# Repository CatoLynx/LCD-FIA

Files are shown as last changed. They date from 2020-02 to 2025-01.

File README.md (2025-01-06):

# What's this?
It's my project of converting an old LCD platform passenger information display to be fully customizable!

# BOMs
The BOM for the FIAControl main controller board can be found [here](https://catolynx.github.io/LCD-FIA/Hardware/FIAControl/bom/ibom.html).

The BOM for the FIAPi Raspberry Pi HAT adapter board can be found [here](https://catolynx.github.io/LCD-FIA/Hardware/FIAPi/bom/ibom.html).

# Pictures
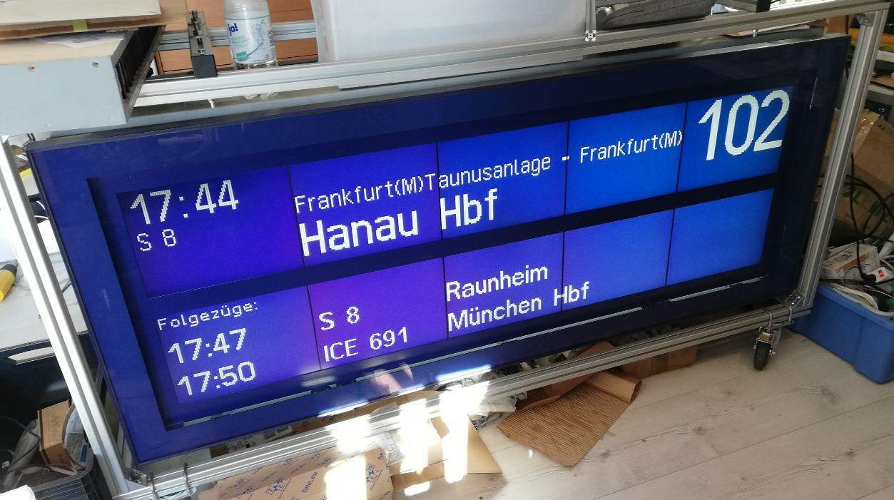
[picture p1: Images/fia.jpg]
A picture of an LCD passenger information display in my room, displaying train departures as if it was in a station


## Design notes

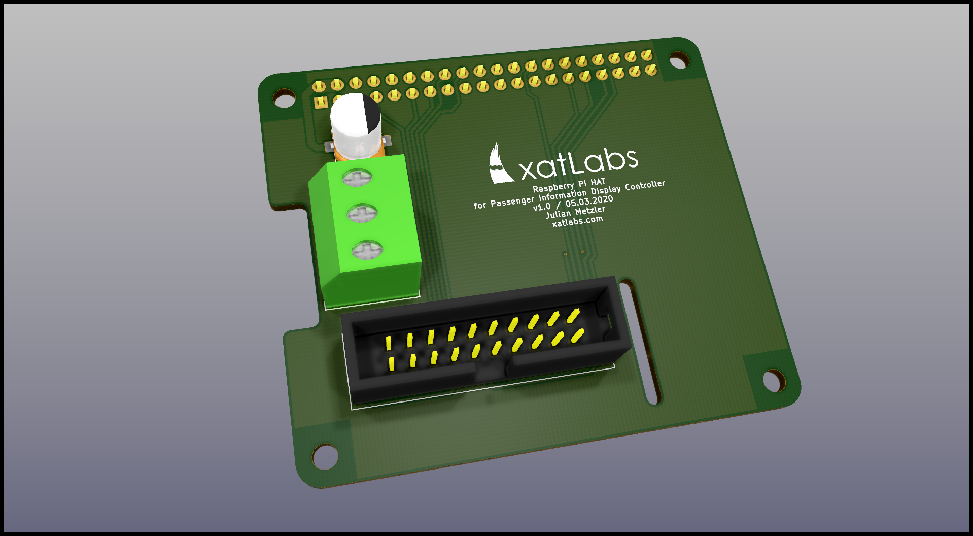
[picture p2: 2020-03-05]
Hardware/FIAPi/Images/3D Front.png

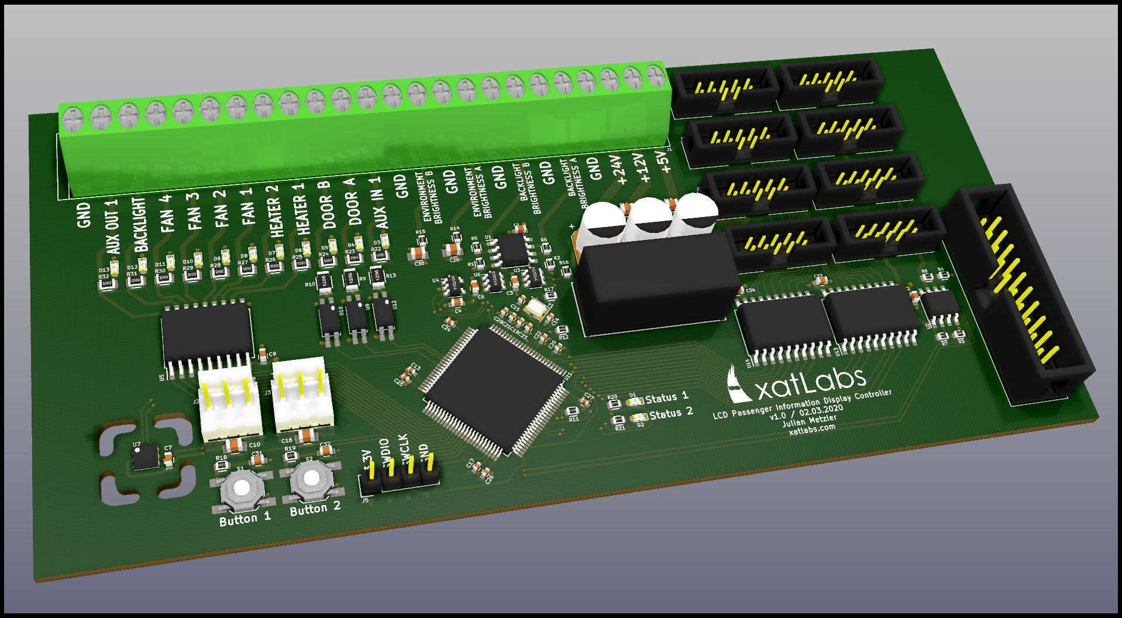
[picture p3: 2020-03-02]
Hardware/FIAControl/Images/3D Front.png

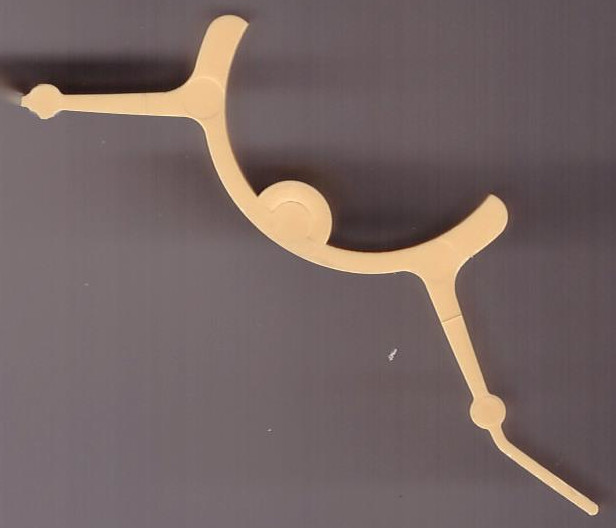
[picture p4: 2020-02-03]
CAD/LCD Klammer Scan.jpg

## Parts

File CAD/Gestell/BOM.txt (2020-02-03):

4x Profil 2060 mm (2x5 Anzeiger)
4x Profil 1810 mm (2x4 Anzeiger)
4x Profil  870 mm
4x Profil  440 mm
2x Profil  520 mm
=        14520 mm (2x5 Anzeiger)
=        13520 mm (2x4 Anzeiger)
24x Winkel
48x Nutenstein
48x Schraube
12x Abdeckkappe

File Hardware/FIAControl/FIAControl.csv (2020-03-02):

Source: | E:\Google Drive\Dokumente\Elektronik\Projekte\funkwerk KJ LCD FIA\Hardware\FIAControl\FIAControl.sch
Date: | 02.03.2020 23:40:50
Tool: | Eeschema (6.0.0-rc1-dev-557-ge985f797c)
Generator: | E:\Google Drive\configfiles\kicad-lib\scripting\plugins\bom_csv_grouped_custom.py
Component Count: | 109
Individual Components:
Item | Qty | Reference(s) | Value | LibPart | Footprint | Datasheet | Comment | Order No.
 |  | C1 | 100n | device:C | Capacitors_SMD:C_0603 | ~
 |  | C2 | 100n | device:C | Capacitors_SMD:C_0603 | ~
 |  | C3 | 100n | device:C | Capacitors_SMD:C_0603 | ~
 |  | C4 | 100n | device:C_Small | Capacitors_SMD:C_0603 | ~
 |  | C5 | 100µ/35V | device:CP | Capacitors_SMD:CP_Elec_6.3x7.7 | ~
 |  | C6 | 100n | device:C | Capacitors_SMD:C_0603 | ~
 |  | C7 | 100n | device:C_Small | Capacitors_SMD:C_0603 | ~
 |  | C8 | 100µ/35V | device:CP | Capacitors_SMD:CP_Elec_6.3x7.7 | ~
 |  | C9 | 100n | device:C | Capacitors_SMD:C_0603 | ~
 |  | C10 | 1µ | device:C_Small | Capacitors_SMD:C_0805 | ~
 |  | C11 | 10µ | device:C | Capacitors_SMD:C_0805 | ~
 |  | C12 | 100µ/35V | device:CP | Capacitors_SMD:CP_Elec_6.3x7.7 | ~
 |  | C13 | 2.2µ | device:C_Small | Capacitors_SMD:C_0402 | ~ | Max. 2Ω ESR
 |  | C14 | 18p | device:C_Small | Capacitors_SMD:C_0402 | ~
 |  | C15 | 18p | device:C_Small | Capacitors_SMD:C_0402 | ~
 |  | C16 | 1µ | device:C_Small | Capacitors_SMD:C_0805 | ~
 |  | C17 | 2.2µ | device:C_Small | Capacitors_SMD:C_0402 | ~ | Max. 2Ω ESR
 |  | C18 | 10µ | device:C | Capacitors_SMD:C_0805 | ~
 |  | C19 | 1µ | device:C_Small | Capacitors_SMD:C_0402 | ~
 |  | C20 | 100n | device:C_Small | Capacitors_SMD:C_0402 | ~
 |  | C21 | 10n | device:C_Small | Capacitors_SMD:C_0402 | ~
 |  | C22 | 100n | device:C_Small | Capacitors_SMD:C_0402 | ~
 |  | C23 | 100n | device:C_Small | Capacitors_SMD:C_0402 | ~
 |  | C24 | 100n | device:C_Small | Capacitors_SMD:C_0402 | ~
 |  | C25 | 100n | device:C_Small | Capacitors_SMD:C_0402 | ~
 |  | C26 | 100n | device:C_Small | Capacitors_SMD:C_0402 | ~
 |  | C27 | 100n | device:C_Small | Capacitors_SMD:C_0402 | ~
 |  | C28 | 1µ | device:C_Small | Capacitors_SMD:C_0805 | ~
 |  | C29 | 100n | device:C_Small | Capacitors_SMD:C_0402 | ~
 |  | C30 | 1µ | device:C_Small | Capacitors_SMD:C_0805 | ~
 |  | C31 | 100n | device:C_Small | Capacitors_SMD:C_0603 | ~
 |  | C32 | 100n | device:C_Small | Capacitors_SMD:C_0603 | ~
 |  | C33 | 100n | device:C_Small | Capacitors_SMD:C_0603 | ~
 |  | C34 | 100n | device:C_Small | Capacitors_SMD:C_0603 | ~
 |  | D1 | Status 1 | device:LED_Small | LEDs:LED_0603 | ~
 |  | D2 | Status 2 | device:LED_Small | LEDs:LED_0603 | ~
 |  | D3 | orange | device:LED | LEDs:LED_0603 | ~
 |  | D4 | orange | device:LED | LEDs:LED_0603 | ~
 |  | D5 | orange | device:LED | LEDs:LED_0603 | ~
 |  | D6 | orange | device:LED | LEDs:LED_0603 | ~
 |  | D7 | orange | device:LED | LEDs:LED_0603 | ~
 |  | D8 | orange | device:LED | LEDs:LED_0603 | ~
 |  | D9 | orange | device:LED | LEDs:LED_0603 | ~
 |  | D10 | orange | device:LED | LEDs:LED_0603 | ~
 |  | D11 | orange | device:LED | LEDs:LED_0603 | ~
 |  | D12 | orange | device:LED | LEDs:LED_0603 | ~
 |  | D13 | orange | device:LED | LEDs:LED_0603 | ~
 |  | J1 | Interface | conn:CONN_01X24 | custom:Connector_DEGSON_DG246-3.81_24pin |  |  | 8x DG246-3.81-03P
 |  | J2 | Temp Sensor 1 | conn:CONN_01X03 | custom:Molex_1718560003
 |  | J3 | Temp Sensor 2 | conn:CONN_01X03 | custom:Molex_1718560003
 |  | J4 | Control | conn:CONN_02X10 | Connectors:IDC_Header_Straight_20pins
 |  | J5 | Debug | conn:CONN_01X04 | Pin_Headers:Pin_Header_Straight_1x04
 |  | J6 | LCD 1 Out | conn:CONN_02X05 | custom:Connector_IDC_2mm_10pin_THT_Straight |  |  | DS1014-10SF1B
 |  | J7 | LCD 1 Loopback | conn:CONN_02X05 | custom:Connector_IDC_2mm_10pin_THT_Straight |  |  | DS1014-10SF1B
 |  | J8 | LCD 3 Out | conn:CONN_02X05 | custom:Connector_IDC_2mm_10pin_THT_Straight |  |  | DS1014-10SF1B
 |  | J9 | LCD 3 Loopback | conn:CONN_02X05 | custom:Connector_IDC_2mm_10pin_THT_Straight |  |  | DS1014-10SF1B
 |  | J10 | LCD 2 Out | conn:CONN_02X05 | custom:Connector_IDC_2mm_10pin_THT_Straight |  |  | DS1014-10SF1B
 |  | J11 | LCD 2 Loopback | conn:CONN_02X05 | custom:Connector_IDC_2mm_10pin_THT_Straight |  |  | DS1014-10SF1B
 |  | J12 | LCD 4 Out | conn:CONN_02X05 | custom:Connector_IDC_2mm_10pin_THT_Straight |  |  | DS1014-10SF1B
 |  | J13 | LCD 4 Loopback | conn:CONN_02X05 | custom:Connector_IDC_2mm_10pin_THT_Straight |  |  | DS1014-10SF1B
 |  | R1 | 22k | device:R | Resistors_SMD:R_0603 | ~
 |  | R2 | 22k | device:R | Resistors_SMD:R_0603 | ~
 |  | R3 | 56k | device:R | Resistors_SMD:R_0603 | ~
 |  | R4 | 56k | device:R | Resistors_SMD:R_0603 | ~
 |  | R5 | 47k | device:R | Resistors_SMD:R_0603 | ~
 |  | R6 | 47k | device:R | Resistors_SMD:R_0603 | ~
 |  | R7 | 91k | device:R | Resistors_SMD:R_0603 | ~
 |  | R8 | 91k | device:R | Resistors_SMD:R_0603 | ~
 |  | R9 | 1.5k | device:R | Resistors_SMD:R_1206 | ~ | ca. 0.32W
 |  | R10 | 1.5k | device:R | Resistors_SMD:R_1206 | ~ | ca. 0.32W
 |  | R11 | 10k | device:R_Small | Resistors_SMD:R_0603 | ~
 |  | R12 | 10k | device:R_Small | Resistors_SMD:R_0603 | ~
 |  | R13 | 1.5k | device:R | Resistors_SMD:R_1206 | ~ | ca. 0.32W
 |  | R14 | 10k | device:R_Small | Resistors_SMD:R_0603 | ~
 |  | R15 | 10k | device:R_Small | Resistors_SMD:R_0603 | ~
 |  | R16 | 4.7k | device:R_Small | Resistors_SMD:R_0603 | ~
 |  | R17 | 4.7k | device:R_Small | Resistors_SMD:R_0603 | ~
 |  | R18 | 1k | device:R_Small | Resistors_SMD:R_0603 | ~
 |  | R19 | 1k | device:R_Small | Resistors_SMD:R_0603 | ~
 |  | R20 | 270R | device:R_Small | Resistors_SMD:R_0603 | ~
 |  | R21 | 270R | device:R_Small | Resistors_SMD:R_0603 | ~
 |  | R22 | 4.7k | device:R | Resistors_SMD:R_0805 | ~ | ca. 0.1W
 |  | R23 | 4.7k | device:R | Resistors_SMD:R_0805 | ~ | ca. 0.1W
 |  | R24 | 4.7k | device:R | Resistors_SMD:R_0805 | ~ | ca. 0.1W
 |  | R25 | 4.7k | device:R | Resistors_SMD:R_0805 | ~ | ca. 0.1W
 |  | R26 | 4.7k | device:R | Resistors_SMD:R_0805 | ~ | ca. 0.1W
 |  | R27 | 4.7k | device:R | Resistors_SMD:R_0805 | ~ | ca. 0.1W
 |  | R28 | 4.7k | device:R | Resistors_SMD:R_0805 | ~ | ca. 0.1W
 |  | R29 | 4.7k | device:R | Resistors_SMD:R_0805 | ~ | ca. 0.1W
 |  | R30 | 4.7k | device:R | Resistors_SMD:R_0805 | ~ | ca. 0.1W
 |  | R31 | 4.7k | device:R | Resistors_SMD:R_0805 | ~ | ca. 0.1W
 |  | R32 | 4.7k | device:R | Resistors_SMD:R_0805 | ~ | ca. 0.1W
 |  | S1 | Button 1 | custom:Switch_small | Buttons_Switches_SMD:SW_SPST_SKQG
 |  | S2 | Button 2 | custom:Switch_small | Buttons_Switches_SMD:SW_SPST_SKQG
 |  | U1 | LM258ADT | Amplifier_Operational:LM358 | Housings_SOIC:SOIC-8_3.9x4.9mm_Pitch1.27mm | http://www.ti.com/lit/ds/symlink/lm2904-n.pdf
 |  | U2 | LM258ADT | Amplifier_Operational:LM358 | Housings_SOIC:SOIC-8_3.9x4.9mm_Pitch1.27mm | http://www.ti.com/lit/ds/symlink/lm2904-n.pdf
 |  | U3 | MCP4726A0 | custom:MCP47x6 | TO_SOT_Packages_SMD:SOT-23-6
 |  | U4 | 24CW160T | custom:EEPROM_I2C_NO_WP | TO_SOT_Packages_SMD:SOT-23-5
 |  | U5 | MIC2981/82YWM | custom:UDN2981A | Housings_SOIC:SOIC-18W_7.5x11.6mm_Pitch1.27mm
 |  | U6 | MCP4726A1 | custom:MCP47x6 | TO_SOT_Packages_SMD:SOT-23-6
 |  | U7 | SHT21 | custom:SHT21 | custom:DFN6_3mmx3mm_EP_P1mm
 |  | U8 | SPAN02A-03 | custom:DCDC_MeanWell_SPAN | custom:DC_DC_Converter_MeanWell_SPAN
 |  | U9 | HMHA2801AR2V | Isolator:PC817 | custom:Optocoupler_MiniFlat_HalfPitch_4pin_SMD | http://www.soselectronic.cz/a_info/resource/d/pc817.pdf
 |  | U10 | HMHA2801AR2V | Isolator:PC817 | custom:Optocoupler_MiniFlat_HalfPitch_4pin_SMD | http://www.soselectronic.cz/a_info/resource/d/pc817.pdf
 |  | U11 | STM32F413VGT6 | MCU_ST_STM32F4:STM32F413VGTx | Housings_QFP:LQFP-100_14x14mm_Pitch0.5mm | http://www.st.com/st-web-ui/static/active/en/resource/technical/document/datasheet/DM00282249.pdf
 |  | U12 | HMHA2801AR2V | Isolator:PC817 | custom:Optocoupler_MiniFlat_HalfPitch_4pin_SMD | http://www.soselectronic.cz/a_info/resource/d/pc817.pdf
 |  | U13 | 74HCT541 | 74xx:74HCT541 | Housings_SOIC:SOIC-20W_7.5x12.8mm_Pitch1.27mm | http://www.ti.com/lit/gpn/sn74HCT541
 |  | U14 | 74HCT541 | 74xx:74HCT541 | Housings_SOIC:SOIC-20W_7.5x12.8mm_Pitch1.27mm | http://www.ti.com/lit/gpn/sn74HCT541
 |  | Y1 | 20MHz | device:Crystal_GND24 | Crystals:Crystal_SMD_2520-4pin_2.5x2.0mm | ~ |  | LFXTAL052896CUTT
Collated Components:
Item | Qty | Reference(s) | Value | LibPart | Footprint | Datasheet | Comment | Order No.
1 | 11 | C1,C2,C3,C4,C6,C7,C9,C31,C32,C33,C34 | 100n | device:C_Small | Capacitors_SMD:C_0603 | ~
2 | 3 | C5,C8,C12 | 100µ/35V | device:CP | Capacitors_SMD:CP_Elec_6.3x7.7 | ~
3 | 4 | C10,C16,C28,C30 | 1µ | device:C_Small | Capacitors_SMD:C_0805 | ~
4 | 2 | C11,C18 | 10µ | device:C | Capacitors_SMD:C_0805 | ~
5 | 2 | C13,C17 | 2.2µ | device:C_Small | Capacitors_SMD:C_0402 | ~ | Max. 2Ω ESR
6 | 2 | C14,C15 | 18p | device:C_Small | Capacitors_SMD:C_0402 | ~
7 | 1 | C19 | 1µ | device:C_Small | Capacitors_SMD:C_0402 | ~
8 | 8 | C20,C22,C23,C24,C25,C26,C27,C29 | 100n | device:C_Small | Capacitors_SMD:C_0402 | ~
9 | 1 | C21 | 10n | device:C_Small | Capacitors_SMD:C_0402 | ~
10 | 1 | D1 | Status 1 | device:LED_Small | LEDs:LED_0603 | ~
11 | 1 | D2 | Status 2 | device:LED_Small | LEDs:LED_0603 | ~
12 | 11 | D3,D4,D5,D6,D7,D8,D9,D10,D11,D12,D13 | orange | device:LED | LEDs:LED_0603 | ~
13 | 1 | J1 | Interface | conn:CONN_01X24 | custom:Connector_DEGSON_DG246-3.81_24pin |  |  | 8x DG246-3.81-03P
14 | 1 | J2 | Temp Sensor 1 | conn:CONN_01X03 | custom:Molex_1718560003
15 | 1 | J3 | Temp Sensor 2 | conn:CONN_01X03 | custom:Molex_1718560003
16 | 1 | J4 | Control | conn:CONN_02X10 | Connectors:IDC_Header_Straight_20pins
17 | 1 | J5 | Debug | conn:CONN_01X04 | Pin_Headers:Pin_Header_Straight_1x04
18 | 1 | J6 | LCD 1 Out | conn:CONN_02X05 | custom:Connector_IDC_2mm_10pin_THT_Straight |  |  | DS1014-10SF1B
19 | 1 | J7 | LCD 1 Loopback | conn:CONN_02X05 | custom:Connector_IDC_2mm_10pin_THT_Straight |  |  | DS1014-10SF1B
20 | 1 | J8 | LCD 3 Out | conn:CONN_02X05 | custom:Connector_IDC_2mm_10pin_THT_Straight |  |  | DS1014-10SF1B
21 | 1 | J9 | LCD 3 Loopback | conn:CONN_02X05 | custom:Connector_IDC_2mm_10pin_THT_Straight |  |  | DS1014-10SF1B
22 | 1 | J10 | LCD 2 Out | conn:CONN_02X05 | custom:Connector_IDC_2mm_10pin_THT_Straight |  |  | DS1014-10SF1B
23 | 1 | J11 | LCD 2 Loopback | conn:CONN_02X05 | custom:Connector_IDC_2mm_10pin_THT_Straight |  |  | DS1014-10SF1B
24 | 1 | J12 | LCD 4 Out | conn:CONN_02X05 | custom:Connector_IDC_2mm_10pin_THT_Straight |  |  | DS1014-10SF1B
25 | 1 | J13 | LCD 4 Loopback | conn:CONN_02X05 | custom:Connector_IDC_2mm_10pin_THT_Straight |  |  | DS1014-10SF1B
26 | 2 | R1,R2 | 22k | device:R | Resistors_SMD:R_0603 | ~
27 | 2 | R3,R4 | 56k | device:R | Resistors_SMD:R_0603 | ~
28 | 2 | R5,R6 | 47k | device:R | Resistors_SMD:R_0603 | ~
29 | 2 | R7,R8 | 91k | device:R | Resistors_SMD:R_0603 | ~
30 | 3 | R9,R10,R13 | 1.5k | device:R | Resistors_SMD:R_1206 | ~ | ca. 0.32W
31 | 4 | R11,R12,R14,R15 | 10k | device:R_Small | Resistors_SMD:R_0603 | ~
32 | 2 | R16,R17 | 4.7k | device:R_Small | Resistors_SMD:R_0603 | ~
33 | 2 | R18,R19 | 1k | device:R_Small | Resistors_SMD:R_0603 | ~
34 | 2 | R20,R21 | 270R | device:R_Small | Resistors_SMD:R_0603 | ~
35 | 11 | R22,R23,R24,R25,R26,R27,R28,R29,R30,R31,R32 | 4.7k | device:R | Resistors_SMD:R_0805 | ~ | ca. 0.1W
36 | 1 | S1 | Button 1 | custom:Switch_small | Buttons_Switches_SMD:SW_SPST_SKQG
37 | 1 | S2 | Button 2 | custom:Switch_small | Buttons_Switches_SMD:SW_SPST_SKQG
38 | 2 | U1,U2 | LM258ADT | Amplifier_Operational:LM358 | Housings_SOIC:SOIC-8_3.9x4.9mm_Pitch1.27mm | http://www.ti.com/lit/ds/symlink/lm2904-n.pdf
39 | 1 | U3 | MCP4726A0 | custom:MCP47x6 | TO_SOT_Packages_SMD:SOT-23-6
40 | 1 | U4 | 24CW160T | custom:EEPROM_I2C_NO_WP | TO_SOT_Packages_SMD:SOT-23-5
41 | 1 | U5 | MIC2981/82YWM | custom:UDN2981A | Housings_SOIC:SOIC-18W_7.5x11.6mm_Pitch1.27mm
42 | 1 | U6 | MCP4726A1 | custom:MCP47x6 | TO_SOT_Packages_SMD:SOT-23-6
43 | 1 | U7 | SHT21 | custom:SHT21 | custom:DFN6_3mmx3mm_EP_P1mm
44 | 1 | U8 | SPAN02A-03 | custom:DCDC_MeanWell_SPAN | custom:DC_DC_Converter_MeanWell_SPAN
45 | 3 | U9,U10,U12 | HMHA2801AR2V | Isolator:PC817 | custom:Optocoupler_MiniFlat_HalfPitch_4pin_SMD | http://www.soselectronic.cz/a_info/resource/d/pc817.pdf
46 | 1 | U11 | STM32F413VGT6 | MCU_ST_STM32F4:STM32F413VGTx | Housings_QFP:LQFP-100_14x14mm_Pitch0.5mm | http://www.st.com/st-web-ui/static/active/en/resource/technical/document/datasheet/DM00282249.pdf
47 | 2 | U13,U14 | 74HCT541 | 74xx:74HCT541 | Housings_SOIC:SOIC-20W_7.5x12.8mm_Pitch1.27mm | http://www.ti.com/lit/gpn/sn74HCT541
48 | 1 | Y1 | 20MHz | device:Crystal_GND24 | Crystals:Crystal_SMD_2520-4pin_2.5x2.0mm | ~ |  | LFXTAL052896CUTT

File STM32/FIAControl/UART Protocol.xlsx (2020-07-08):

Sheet: General Information
Frame Structure
Pos. | Value | Description
1 | 0xFF | Start Byte
2 |  | Message length (all following bytes)
3 … n-1 |  | Payload
n |  | Checksum (XOR across all payload bytes, start value 0x7F)

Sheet: UART Commands
UART Commands
Group | Command | Name | Payload Length | Response Payload Length | Description
System | 0x00 | NULL | 0 | 1 | Dummy command. Response: Byte 0 - Always 0xFF
 | 0x01 | MCU_RESET | 0 | 0 | Initiate a system reset. No response since the system will immediately reset.
Lights | 0x10 | SET_BACKLIGHT_STATE | 1 | 0 | Set / Get backlight state. Parameters: Byte 0 - Backlight state (0 = OFF, 1 = ON)
 | 0x11 | GET_BACKLIGHT_STATE | 0 | 1
 | 0x12 | SET_BACKLICHT_BASE_BRIGHTNESS | 4 | 0 | Set / Get base value for backlight auto-brightness. (0 to 4095) Parameters: Byte 0 - Side A brightness high byte Byte 1 - Side A brightness low byte Byte 2 - Side B brightness high byte Byte 3 - Side B brightness low byte
 | 0x13 | GET_BACKLIGHT_BASE_BRIGHTNESS | 0 | 4
 | 0x14 | GET_BACKLIGHT_BRIGHTNESS | 0 | 4 | Set / Get current backlight brightness. (0 to 4095) Parameters: Byte 0 - Side A brightness high byte Byte 1 - Side A brightness low byte Byte 2 - Side B brightness high byte Byte 3 - Side B brightness low byte
Heat Management | 0x20 | SET_HEATERS_STATE | 1 | 0 | Set / Get heaters state. Parameters: Byte 0 - Heaters state (0 = OFF, 1 = HALF POWER, 2 = FULL POWER)
 | 0x21 | GET_HEATERS_STATE | 0 | 1
 | 0x22 | SET_CIRCULATION_FANS_STATE | 1 | 0 | Set / Get circulation fans state. Parameters: Byte 0 - Circulation fans state (0 = OFF, 1 = HALF POWER, 2 = FULL POWER)
 | 0x23 | GET_CIRCULATION_FANS_STATE | 0 | 1
 | 0x24 | SET_HEAT_EXCHANGER_FAN_STATE | 0 | 1 | Set / Get heat exchanger fan state. Parameters: Byte 0 - Heat exchanger fan state (0 = OFF, 1 = ON)
 | 0x25 | GET_HEAT_EXCHANGER_FAN_STATE | 1 | 0
 | 0x26 | SET_BACKLIGHT_BALLAST_FANS_STATE | 0 | 1 | Set / Get heat backlight ballast fans state. Parameters: Byte 0 - Backlight ballast fans state (0 = OFF, 1 = ON)
 | 0x27 | GET_BACKLIGHT_BALLAST_FANS_STATE | 1 | 0
Doors | 0x30 | GET_DOOR_STATES | 0 | 1 | Get door states. Parameters: Byte 0 - Door states (Bit 0 = Door A, Bit 1 = Door B; 0 = CLOSED, 1 = OPEN)
Sensors | 0x40 | GET_TEMPERATURES | 0 | 8 | Get temperature readings of internal sensors. All values are in 1/100 °C. Parameters: Byte 0 - External sensor 1 high byte Byte 1 - External sensor 1 low byte Byte 2 - External sensor 2 high byte Byte 3 - External sensor 2 low byte Byte 4 - On-board sensor high byte Byte 5 - On-board sensor low byte Byte 6 - MCU sensor high byte Byte 7 - MCU sensor low byte
 | 0x41 | GET_HUMIDITY | 0 | 2 | Get internal humidity reading from on-board sensor. Value is in 1/100 %RH. Parameters: Byte 0 - Humidity high byte Byte 1 - Humidity low byte
 | 0x42 | GET_ENV_BRIGHTNESS | 0 | 4 | Get environment brightness reading from integrated brightness sensors. (0 to 4095) Parameters: Byte 0 - Side A brightness high byte Byte 1 - Side A brightness low byte Byte 2 - Side B brightness high byte Byte 3 - Side B brightness low byte
LCDs | 0x50 | SET_LCD_CONTRAST | 4 | 0 | Set / Get current LCD contrast. (0 to 4095) Parameters: Byte 0 - Side A contrast high byte Byte 1 - Side A contrast low byte Byte 2 - Side B contrast high byte Byte 3 - Side B contrast low byte
 | 0x51 | GET_LCD_CONTRAST | 0 | 4
 | 0x60 | CREATE_SCROLL_BUFFER | 25 | 1 | Create a scroll buffer. Position and size values are in pixels. X and Y are counted from the top-left corner of the display. Parameters: Byte 0 - Display X position high byte Byte 1 - Display side Byte 2 - Display X position low byte Byte 3 - Display Y position high byte Byte 4 - Dispaly Y position low byte Byte 5 - Display width high byte Byte 6 - Display width low byte Byte 7 - Display height high byte Byte 8 - Display height low byte Byte 9 - Internal width high byte Byte 10 - Internal width low byte Byte 11 - Internal height high byte Byte 12 - Internal height low byte Byte 13 - Scroll offset X high byte Byte 14 - Scroll offset X low byte Byte 15 - Scroll offset Y high byte Byte 16 - Scroll offset Y low byte Byte 17 - Scroll speed X high byte Byte 18 - Scroll speed X low byte Byte 19 - Scroll speed Y high byte Byte 20 - Scroll speed Y low byte Byte 21 - Scroll step X high byte Byte 22 - Scroll step X low byte Byte 23 - Scroll step Y high byte Byte 24 - Scroll step Y low byte Response: Byte 0 - The ID of the created buffer or 0 on failure
 | 0x61 | DELETE_SCROLL_BUFFER | 1 | 1 | Delete a scroll buffer. Parameters: Byte 0 - The ID of the buffer to be deleted Response: Byte 0 - 1 on success, 0 on failure
 | 0x62 | UPDATE_SCROLL_BUFFER | 22 | 1 | Update parameters of a scroll buffer. Position and size values are in pixels. X and Y are counted from the top-left corner of the display. Set any value to 0xFFFF (0x7FFF for scroll steps) to leave unchanged. Parameters: Byte 0 - The ID of the buffer to be updated Byte 1 - Display side Byte 2 - Display X position high byte Byte 3 - Display X position low byte Byte 4 - Display Y position high byte Byte 5 - Dispaly Y position low byte Byte 6 - Display width high byte Byte 7 - Display width low byte Byte 8 - Display height high byte Byte 9 - Display height low byte Byte 10 - Scroll offset X high byte Byte 11 - Scroll offset X low byte Byte 12 - Scroll offset Y high byte Byte 13 - Scroll offset Y low byte Byte 14 - Scroll speed X high byte Byte 15 - Scroll speed X low byte Byte 16 - Scroll speed Y high byte Byte 17 - Scroll speed Y low byte Byte 18 - Scroll step X high byte Byte 19 - Scroll step X low byte Byte 20 - Scroll step Y high byte Byte 21 - Scroll step Y low byte Response: Byte 0 - 1 on success, 0 on failure
 | 0x63 | SET_DESTINATION_BUFFER | 1 | 1 | Set the SPI destination buffer. Parameters: Byte 0 - The ID of the destination buffer Response: Byte 0 - 1 on success, 0 on failure
 | 0x64 | GET_DESTINATION_BUFFER | 0 | 1 | Get the SPI destination buffer. Response: Byte 0 - The buffer ID as expected by SET_DESTINATION_BUFFER
 | 0x65 | SET_MASK_ENABLED | 1 | 0 | Set mask compositing on or off. Parameters: Byte 0 - 1 for on, 0 for off
 | 0x66 | GET_MASK_ENABLED | 0 | 1 | Return mask compositing state. Response: Byte 0 - 1 for on, 0 for off

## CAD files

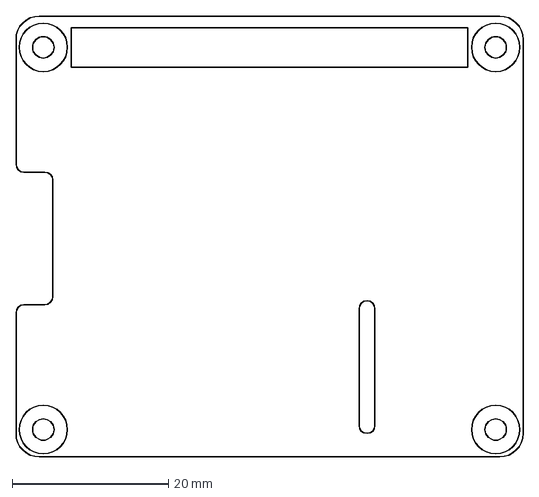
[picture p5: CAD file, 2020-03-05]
Hardware/FIAPi/HAT.dxf
65.0 x 56.5 mm

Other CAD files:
CAD/Gestell/Anzeiger Typ 5.STL
CAD/Gestell/Gestell.STL
CAD/LCD Klammer.STL
CAD/LCD Klammer.dxf

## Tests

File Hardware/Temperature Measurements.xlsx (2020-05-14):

Time | Temp. Backlight Ballasts | Temp. Airflow | Temp. Board | Temp. MCU | Rel. Humidity
0 | 32.31 | 28.25 | 32.11 | 32.7 | 17.89
5.02286005 | 32.25 | 28.25 | 32.1 | 32.7 | 17.89
10.04397988 | 32.25 | 28.25 | 32.1 | 32.7 | 17.86
15.06609988 | 32.18 | 28.25 | 32.1 | 33.02 | 17.86
20.08723998 | 32.18 | 28.18 | 32.1 | 33.02 | 17.86
25.10895991 | 32.12 | 28.25 | 32.21 | 33.02 | 17.86
30.13077998 | 32.12 | 28.18 | 32.21 | 33.35 | 17.74
35.1519599 | 32.12 | 28.25 | 32.21 | 33.35 | 17.74
40.1742599 | 32.12 | 28.25 | 32.21 | 33.35 | 17.74
45.19580984 | 32.12 | 28.25 | 32.3 | 33.35 | 17.74
50.21706986 | 32.18 | 28.25 | 32.3 | 33.35 | 17.7
55.23914003 | 32.18 | 28.25 | 32.3 | 33.35 | 17.7
60.26086998 | 32.25 | 28.25 | 32.3 | 33.35 | 17.7
65.28291988 | 32.31 | 28.18 | 32.26 | 33.35 | 17.7
70.30535984 | 32.37 | 28.25 | 32.26 | 33.35 | 17.78
75.32747984 | 32.37 | 28.25 | 32.26 | 33.35 | 17.78
80.34875989 | 32.5 | 28.25 | 32.26 | 33.35 | 17.78
85.36996984 | 32.56 | 28.25 | 32.22 | 33.35 | 17.78
90.39227986 | 32.62 | 28.31 | 32.22 | 33.35 | 17.86
95.41399002 | 32.75 | 28.25 | 32.22 | 33.35 | 17.86
100.4358299 | 32.81 | 28.31 | 32.22 | 33.35 | 17.86
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

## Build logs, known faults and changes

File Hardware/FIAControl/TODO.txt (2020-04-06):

- Contrast OP-Amp: Must be more powerful and source / sink current
- OneWire: Missing pull-up resistors
- Env. Backlight input: Doesn't go down to 0V
- Change peripheral connectors (maybe even use pluggable connectors)

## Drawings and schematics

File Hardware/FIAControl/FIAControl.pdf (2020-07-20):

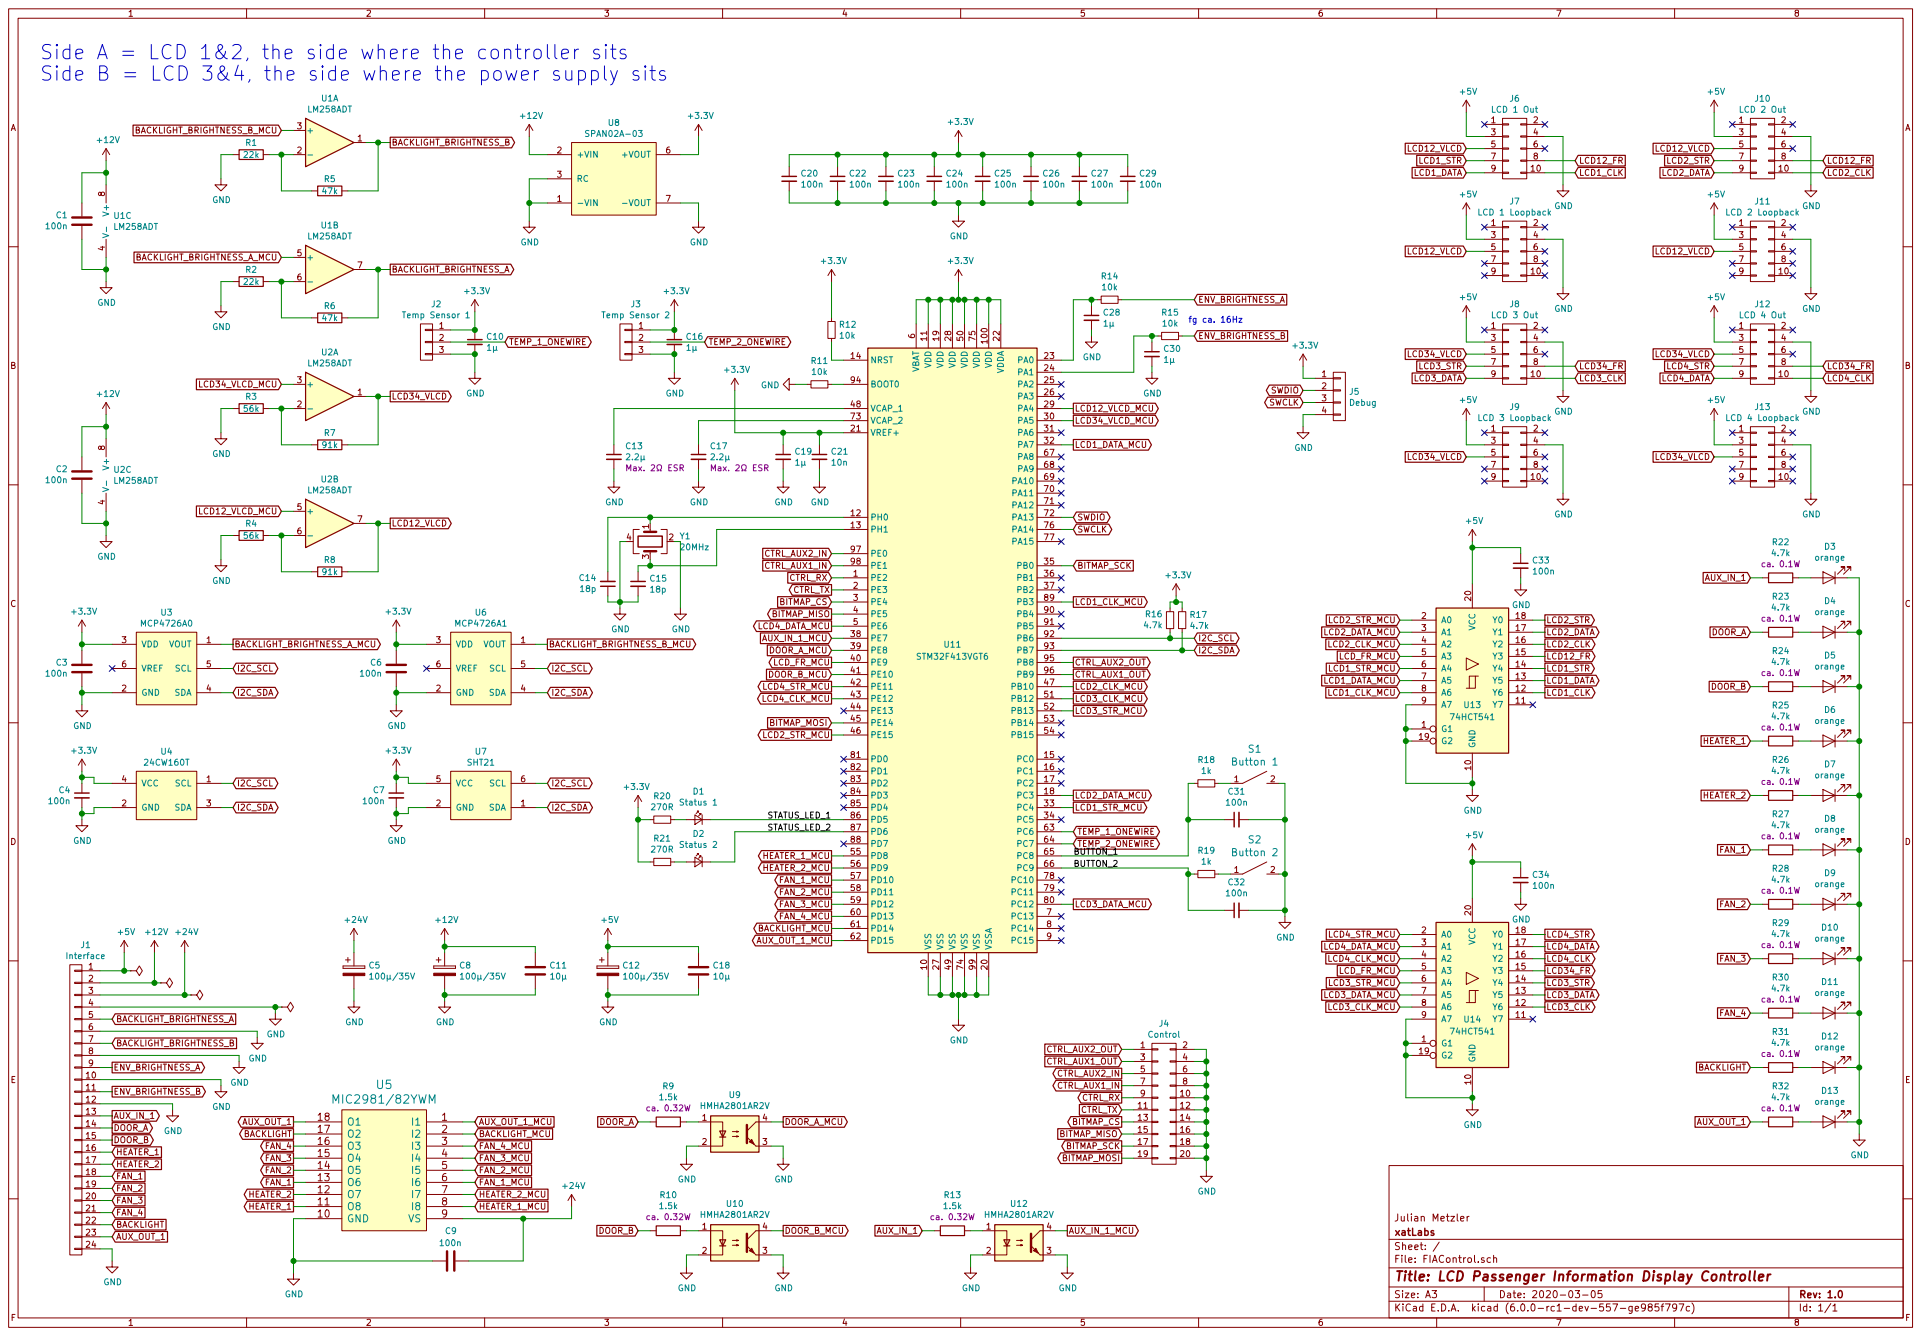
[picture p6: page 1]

LCD12_VLCD_MCU Side A = LCD 1&2, the side where the controller sits
Side B = LCD 3&4, the side where the power supply sits

6 VCAP_1 48 VCAP_2 73 VDD 100 VDD 11 VDD 19 VDD 28 VDD 50 VDD 75 VDDA 22 VREF+ 21 VSS 10 VSS 27 VSS 49 VSS 74 VSS 99 VSSA 20 U11 STM32F413VGT6 GND

Julian Metzler
Id: 1/1 Title: LCD Passenger Information Display Controller File: FIAControl.sch Sheet: / xatLabs

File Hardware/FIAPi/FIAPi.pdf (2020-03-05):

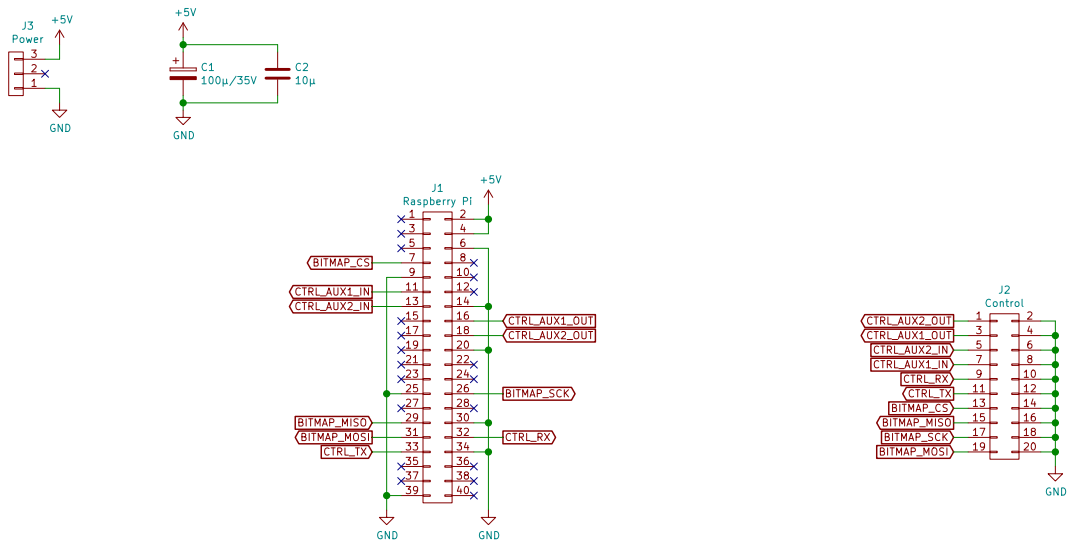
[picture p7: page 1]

Julian Metzler
File: FIAPi.sch Sheet: / xatLabs

Id: 1/1 Title: FIA Raspberry Pi HAT

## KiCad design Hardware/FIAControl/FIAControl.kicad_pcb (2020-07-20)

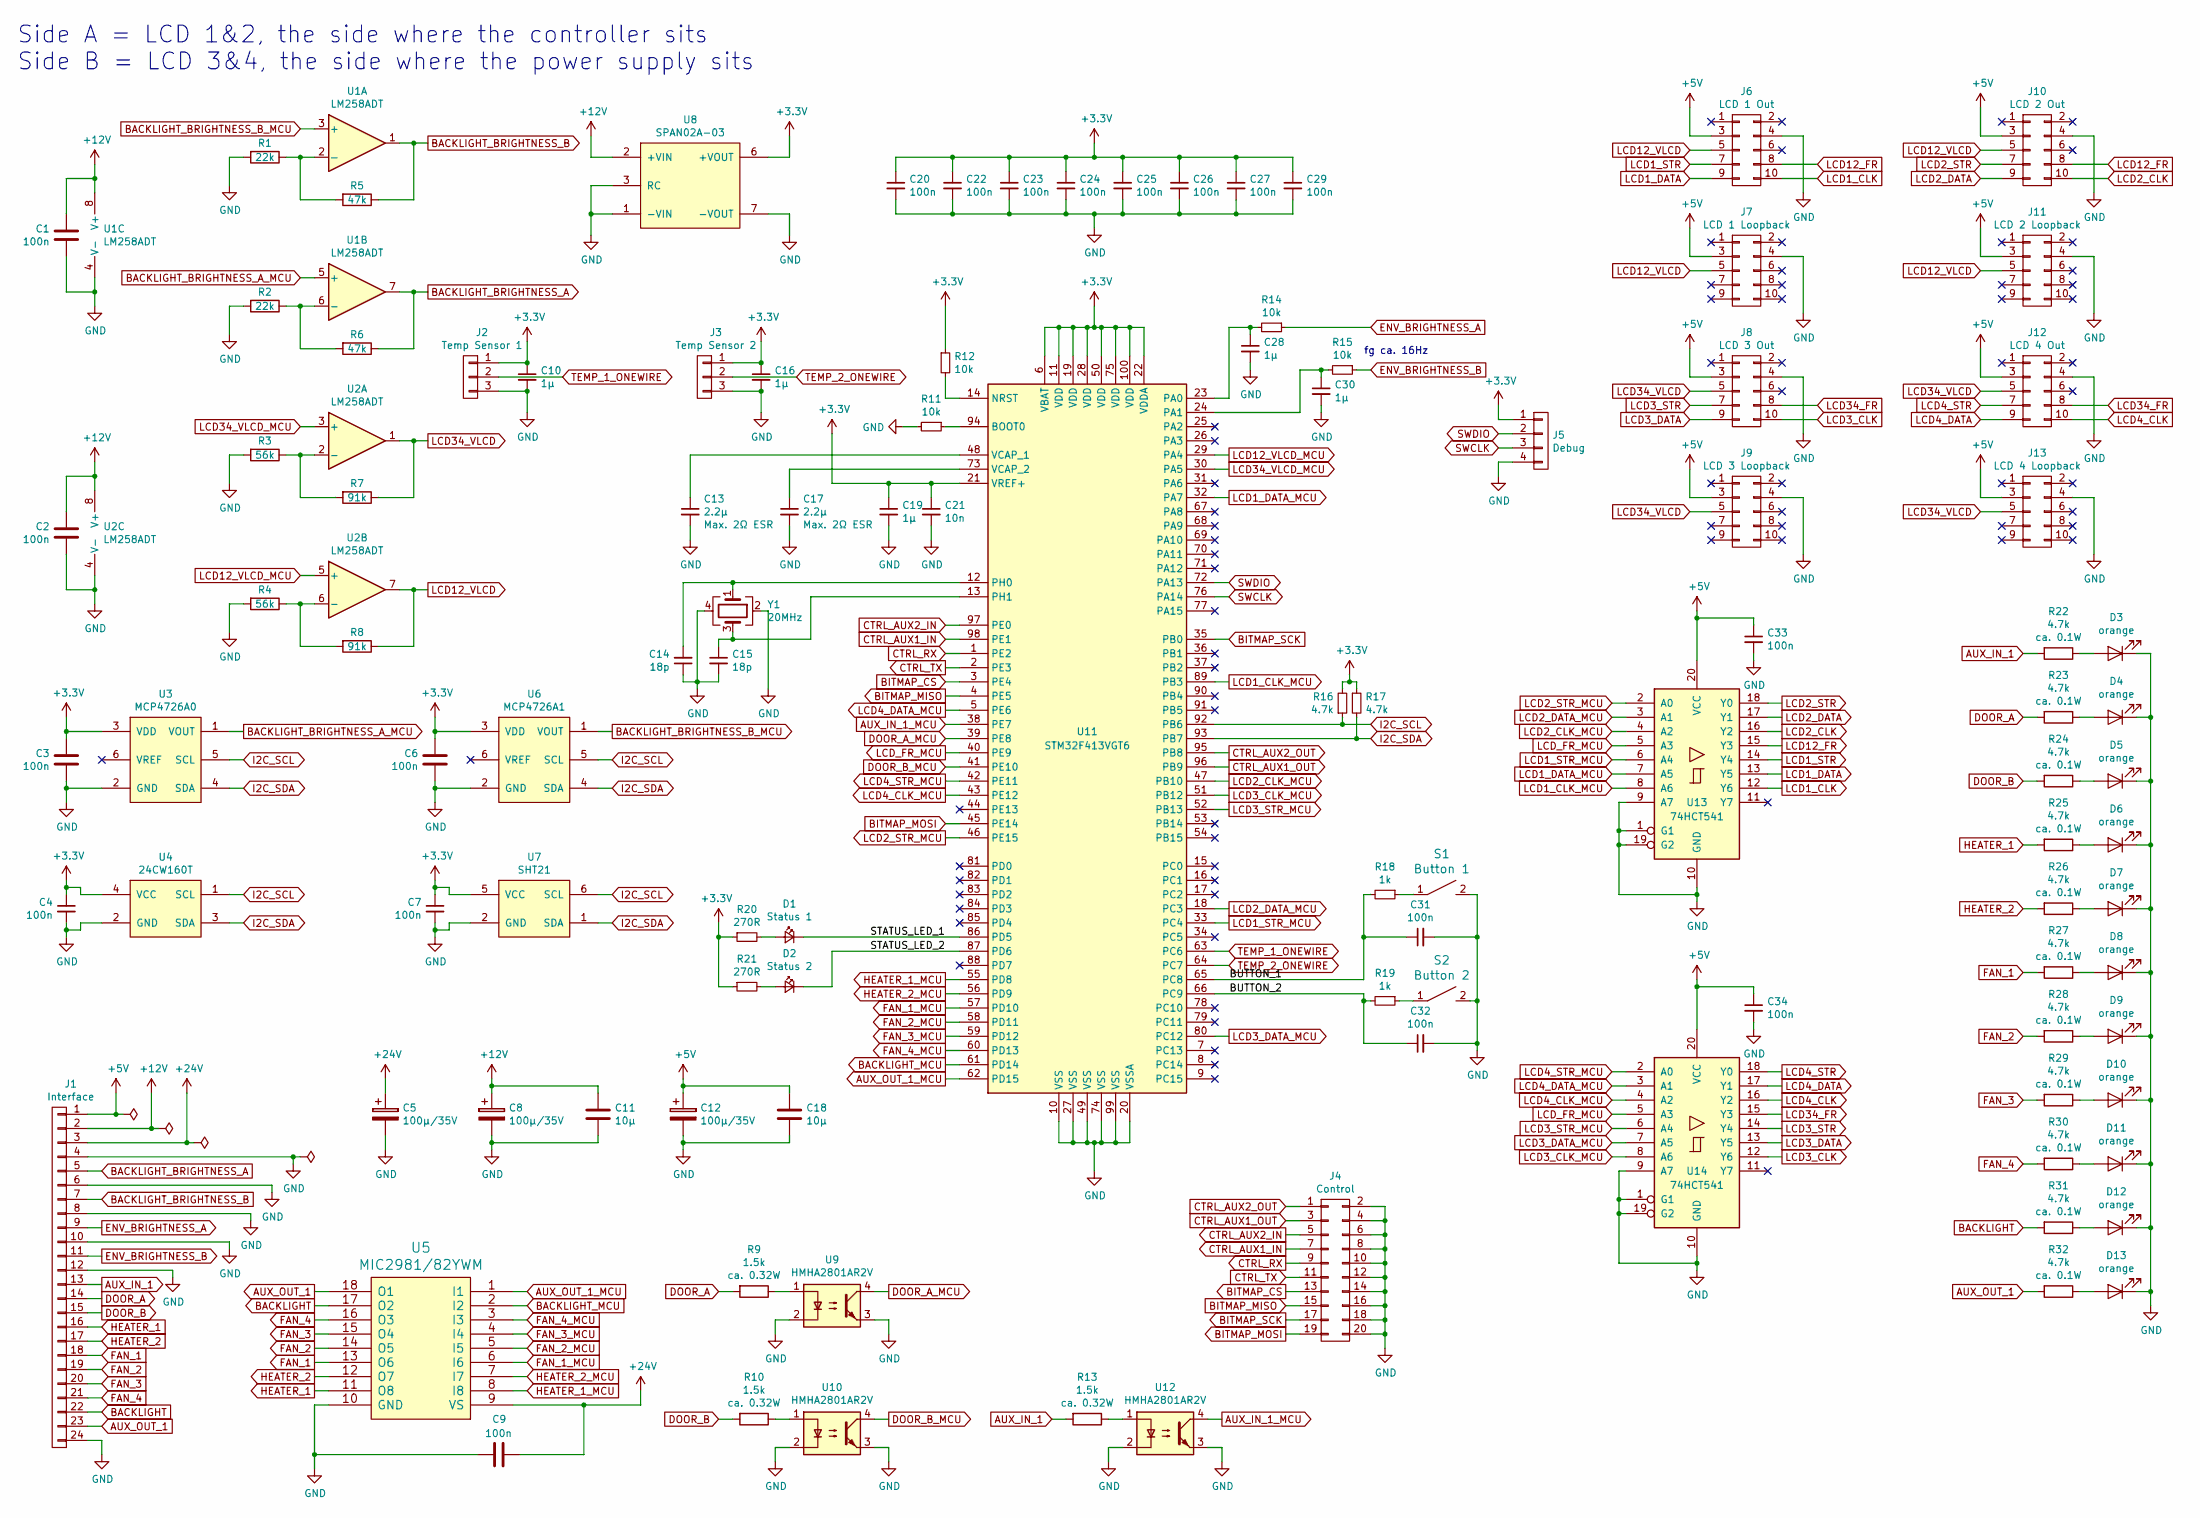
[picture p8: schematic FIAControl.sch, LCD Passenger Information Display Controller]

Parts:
C1, C2, C3, C4, C6, C7, C9, C31, C32, C33, C34: 100n; C_0603
C5, C8, C12: 100µ/35V; CP_Elec_6.3x7.7
C10, C16, C28, C30: 1µ; C_0805
C11, C18: 10µ; C_0805
C13, C17: 2.2µ; C_0402
C14, C15: 18p; C_0402
C19: 1µ; C_0402
C20, C22, C23, C24, C25, C26, C27, C29: 100n; C_0402
C21: 10n; C_0402
D1: Status 1; LED_0603
D2: Status 2; LED_0603
D3, D4, D5, D6, D7, D8, D9, D10, D11, D12, D13: orange; LED_0603
J1: Interface; Connector_DEGSON_DG246-3.81_24pin
J2: Temp Sensor 1; Molex_1718560003
J3: Temp Sensor 2; Molex_1718560003
J4: Control; IDC_Header_Straight_20pins
J5: Debug; Pin_Header_Straight_1x04
J6: LCD 1 Out; Connector_IDC_2mm_10pin_THT_Straight
J7: LCD 1 Loopback; Connector_IDC_2mm_10pin_THT_Straight
J8: LCD 3 Out; Connector_IDC_2mm_10pin_THT_Straight
J9: LCD 3 Loopback; Connector_IDC_2mm_10pin_THT_Straight
J10: LCD 2 Out; Connector_IDC_2mm_10pin_THT_Straight
J11: LCD 2 Loopback; Connector_IDC_2mm_10pin_THT_Straight
J12: LCD 4 Out; Connector_IDC_2mm_10pin_THT_Straight
J13: LCD 4 Loopback; Connector_IDC_2mm_10pin_THT_Straight
R1, R2: 22k; R_0603
R3, R4: 56k; R_0603
R5, R6: 47k; R_0603
R7, R8: 91k; R_0603
R9, R10, R13: 1.5k; R_1206
R11, R12, R14, R15: 10k; R_0603
R16, R17: 4.7k; R_0603
R18, R19: 1k; R_0603
R20, R21: 270R; R_0603
R22, R23, R24, R25, R26, R27, R28, R29, R30, R31, R32: 4.7k; R_0805
S1: Button 1; SW_SPST_SKQG
S2: Button 2; SW_SPST_SKQG
U1, U2: LM258ADT; SOIC-8_3.9x4.9mm_Pitch1.27mm
U3: MCP4726A0; SOT-23-6
U4: 24CW160T; SOT-23-5
U5: MIC2981/82YWM; SOIC-18W_7.5x11.6mm_Pitch1.27mm
U6: MCP4726A1; SOT-23-6
U7: SHT21; DFN6_3mmx3mm_EP_P1mm
U8: SPAN02A-03; DC_DC_Converter_MeanWell_SPAN
U9, U10, U12: HMHA2801AR2V; Optocoupler_MiniFlat_HalfPitch_4pin_SMD
U11: STM32F413VGT6; LQFP-100_14x14mm_Pitch0.5mm
U13, U14: 74HCT541; SOIC-20W_7.5x12.8mm_Pitch1.27mm
Y1: 20MHz; Crystal_SMD_2520-4pin_2.5x2.0mm

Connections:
+3V3: C3.2, C4.1, C6.2, C7.1, C10.1, C16.1, C19.1, C20.1, C21.1, C22.1, C23.1, C24.1, C25.1, C26.1, C27.1, C29.1, J2.1, J3.1, J5.1, R12.1, R16.2, R17.1, R20.1, R21.1, U3.3 (VDD), U4.4 (VCC), U6.3 (VDD), U7.5 (VCC), U8.6 (+VOUT), U11.6 (VBAT), U11.11 (VDD), U11.19 (VDD), U11.21 (VREF+), U11.22 (VDDA), U11.28 (VDD), U11.50 (VDD), U11.75 (VDD), U11.100 (VDD)
+5V: C12.1, C18.1, C33.1, C34.1, J1.1, J6.3, J7.3, J8.3, J9.3, J10.3, J11.3, J12.3, J13.3, U13.20 (VCC), U14.20 (VCC)
+12V: C1.2, C2.2, C8.1, C11.1, J1.2, U1.8 (V+), U2.8 (V+), U8.2 (+VIN)
+24V: C5.1, C9.2, J1.3, U5.9 (VS)
/BUTTON_1: C31.1, R18.2, U11.65 (PC8)
/BUTTON_2: C32.1, R19.2, U11.66 (PC9)
/STATUS_LED_1: D1.1 (K), U11.86 (PD5)
/STATUS_LED_2: D2.1 (K), U11.87 (PD6)
AUX_IN_1: J1.13, R13.2, R22.2
AUX_IN_1_MCU: U11.38 (PE7), U12.4
AUX_OUT_1: J1.23, R32.2, U5.18 (O1)
AUX_OUT_1_MCU: U5.1 (I1), U11.62 (PD15)
BACKLIGHT: J1.22, R31.2, U5.17 (O2)
BACKLIGHT_BRIGHTNESS_A: J1.5, R6.1, U1.7
BACKLIGHT_BRIGHTNESS_A_MCU: U1.5 (+), U3.1 (VOUT)
BACKLIGHT_BRIGHTNESS_B: J1.7, R5.1, U1.1
BACKLIGHT_BRIGHTNESS_B_MCU: U1.3 (+), U6.1 (VOUT)
BACKLIGHT_MCU: U5.2 (I2), U11.61 (PD14)
BITMAP_CS: J4.13, U11.3 (PE4)
BITMAP_MISO: J4.15, U11.4 (PE5)
BITMAP_MOSI: J4.19, U11.45 (PE14)
BITMAP_SCK: J4.17, U11.35 (PB0)
CTRL_AUX1_IN: J4.7, U11.98 (PE1)
CTRL_AUX1_OUT: J4.3, U11.96 (PB9)
CTRL_AUX2_IN: J4.5, U11.97 (PE0)
CTRL_AUX2_OUT: J4.1, U11.95 (PB8)
CTRL_RX: J4.9, U11.1 (PE2)
CTRL_TX: J4.11, U11.2 (PE3)
DOOR_A: J1.14, R9.2, R23.2
DOOR_A_MCU: U9.4, U11.39 (PE8)
DOOR_B: J1.15, R10.2, R24.2
DOOR_B_MCU: U10.4, U11.41 (PE10)
ENV_BRIGHTNESS_A: J1.9, R14.1
ENV_BRIGHTNESS_B: J1.11, R15.1
FAN_1: J1.18, R27.2, U5.13 (O6)
FAN_1_MCU: U5.6 (I6), U11.57 (PD10)
FAN_2: J1.19, R28.2, U5.14 (O5)
FAN_2_MCU: U5.5 (I5), U11.58 (PD11)
FAN_3: J1.20, R29.2, U5.15 (O4)
FAN_3_MCU: U5.4 (I4), U11.59 (PD12)
FAN_4: J1.21, R30.2, U5.16 (O3)
FAN_4_MCU: U5.3 (I3), U11.60 (PD13)
GND: C1.1, C2.1, C3.1, C4.2, C5.2, C6.1, C7.2, C8.2, C9.1, C10.2, C11.2, C12.2, C13.2, C14.1, C15.2, C16.2, C17.2, C18.2, C19.2, C20.2, C21.2, C22.2, C23.2, C24.2, C25.2, C26.2, C27.2, C28.2, C29.2, C30.2, C31.2, C32.2, C33.2, C34.2, D3.1 (K), D4.1 (K), D5.1 (K), D6.1 (K), D7.1 (K), D8.1 (K), D9.1 (K), D10.1 (K), D11.1 (K), D12.1 (K), D13.1 (K), J1.4, J1.6, J1.8, J1.10, J1.12, J1.24, J2.3, J3.3, J4.2, J4.4, J4.6, J4.8, J4.10, J4.12, J4.14, J4.16, J4.18, J4.20, J5.4, J6.4, J7.4, J8.4, J9.4, J10.4, J11.4, J12.4, J13.4, R1.2, R2.2, R3.2, R4.2, R11.2, S1.2, S2.2, U1.4 (V-), U2.4 (V-), U3.2 (GND), U4.2 (GND), U5.10 (GND), U6.2 (GND), U7.2 (GND), U8.1 (-VIN), U8.3 (RC), U8.7 (-VOUT), U9.2, U9.3, U10.2, U10.3, U11.10 (VSS), U11.20 (VSSA), U11.27 (VSS), U11.49 (VSS), U11.74 (VSS), U11.99 (VSS), U12.2, U12.3, U13.1 (G1), U13.9 (A7), U13.10 (GND), U13.19 (G2), U14.1 (G1), U14.9 (A7), U14.10 (GND), U14.19 (G2), Y1.2, Y1.4
HEATER_1: J1.16, R25.2, U5.11 (O8)
HEATER_1_MCU: U5.8 (I8), U11.55 (PD8)
HEATER_2: J1.17, R26.2, U5.12 (O7)
HEATER_2_MCU: U5.7 (I7), U11.56 (PD9)
I2C_SCL: R16.1, U3.5 (SCL), U4.1 (SCL), U6.5 (SCL), U7.6 (SCL), U11.92 (PB6)
I2C_SDA: R17.2, U3.4 (SDA), U4.3 (SDA), U6.4 (SDA), U7.1 (SDA), U11.93 (PB7)
LCD1_CLK: J6.10, U13.12 (Y6)
LCD1_CLK_MCU: U11.89 (PB3), U13.8 (A6)
LCD1_DATA: J6.9, U13.13 (Y5)
LCD1_DATA_MCU: U11.32 (PA7), U13.7 (A5)
LCD1_STR: J6.7, U13.14 (Y4)
LCD1_STR_MCU: U11.33 (PC4), U13.6 (A4)
LCD2_CLK: J10.10, U13.16 (Y2)
LCD2_CLK_MCU: U11.47 (PB10), U13.4 (A2)
LCD2_DATA: J10.9, U13.17 (Y1)
LCD2_DATA_MCU: U11.18 (PC3), U13.3 (A1)
LCD2_STR: J10.7, U13.18 (Y0)
LCD2_STR_MCU: U11.46 (PE15), U13.2 (A0)
LCD3_CLK: J8.10, U14.12 (Y6)
LCD3_CLK_MCU: U11.51 (PB12), U14.8 (A6)
LCD3_DATA: J8.9, U14.13 (Y5)
LCD3_DATA_MCU: U11.80 (PC12), U14.7 (A5)
LCD3_STR: J8.7, U14.14 (Y4)
LCD3_STR_MCU: U11.52 (PB13), U14.6 (A4)
LCD4_CLK: J12.10, U14.16 (Y2)
LCD4_CLK_MCU: U11.43 (PE12), U14.4 (A2)
LCD4_DATA: J12.9, U14.17 (Y1)
LCD4_DATA_MCU: U11.5 (PE6), U14.3 (A1)
LCD4_STR: J12.7, U14.18 (Y0)
LCD4_STR_MCU: U11.42 (PE11), U14.2 (A0)
LCD12_FR: J6.8, J10.8, U13.15 (Y3)
LCD12_VLCD: J6.5, J7.5, J10.5, J11.5, R8.1, U2.7
LCD12_VLCD_MCU: U2.5 (+), U11.29 (PA4)
LCD34_FR: J8.8, J12.8, U14.15 (Y3)
LCD34_VLCD: J8.5, J9.5, J12.5, J13.5, R7.1, U2.1
LCD34_VLCD_MCU: U2.3 (+), U11.30 (PA5)
LCD_FR_MCU: U11.40 (PE9), U13.5 (A3), U14.5 (A3)
unnamed: C13.1, U11.48 (VCAP_1)
unnamed: C14.2, U11.12 (PH0), Y1.1
unnamed: C15.1, U11.13 (PH1), Y1.3
unnamed: C17.1, U11.73 (VCAP_2)
unnamed: C28.1, R14.2, U11.23 (PA0)
unnamed: C30.1, R15.2, U11.24 (PA1)
unnamed: D1.2 (A), R20.2
unnamed: D2.2 (A), R21.2
unnamed: D3.2 (A), R22.1
unnamed: D4.2 (A), R23.1
unnamed: D5.2 (A), R24.1
unnamed: D6.2 (A), R25.1
unnamed: D7.2 (A), R26.1
unnamed: D8.2 (A), R27.1
unnamed: D9.2 (A), R28.1
unnamed: D10.2 (A), R29.1
unnamed: D11.2 (A), R30.1
unnamed: D12.2 (A), R31.1
unnamed: D13.2 (A), R32.1
unnamed: R1.1, R5.2, U1.2 (-)
unnamed: R2.1, R6.2, U1.6 (-)
unnamed: R3.1, R7.2, U2.2 (-)
unnamed: R4.1, R8.2, U2.6 (-)
unnamed: R9.1, U9.1
unnamed: R10.1, U10.1
unnamed: R11.1, U11.94 (BOOT0)
unnamed: R12.2, U11.14 (NRST)
unnamed: R13.1, U12.1
unnamed: R18.1, S1.1
unnamed: R19.1, S2.1
SWCLK: J5.3, U11.76 (PA14)
SWDIO: J5.2, U11.72 (PA13)
TEMP_1_ONEWIRE: J2.2, U11.63 (PC6)
TEMP_2_ONEWIRE: J3.2, U11.64 (PC7)

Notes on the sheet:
Side A = LCD 1&2, the side where the controller sits Side B = LCD 3&4, the side where the power supply sits
fg ca. 16Hz

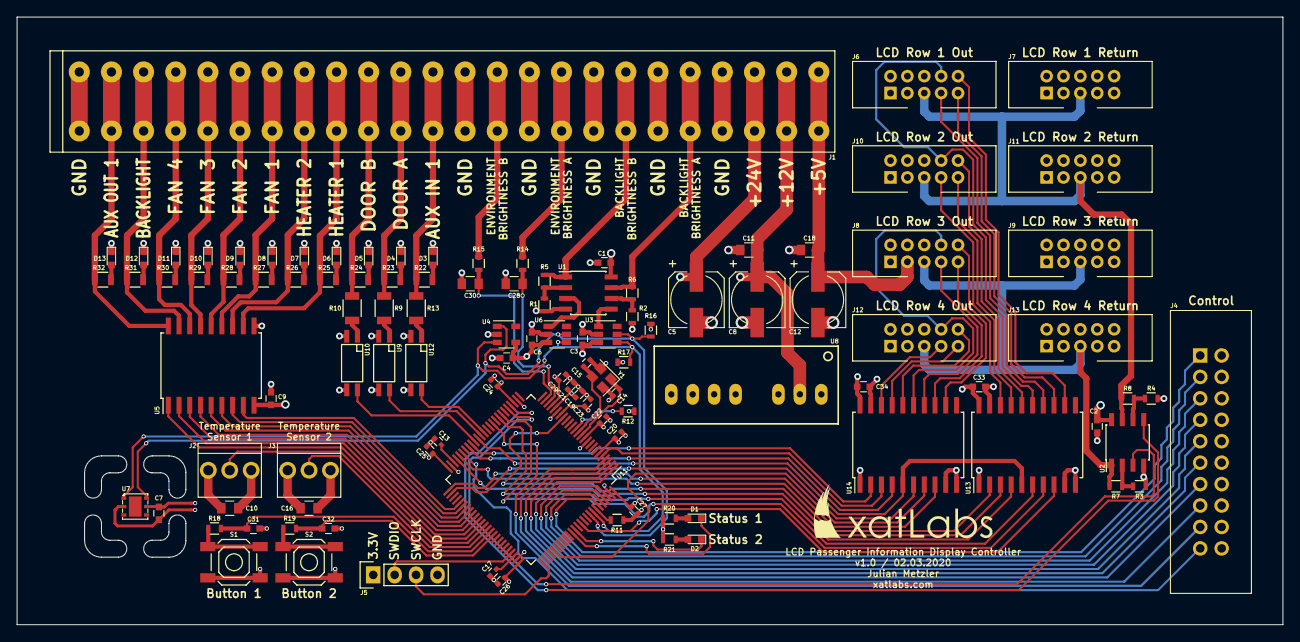
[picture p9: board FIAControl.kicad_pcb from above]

Board: 4 copper layers, 150.0 x 72.0 mm, 109 parts (0 on the bottom side), 114 nets.

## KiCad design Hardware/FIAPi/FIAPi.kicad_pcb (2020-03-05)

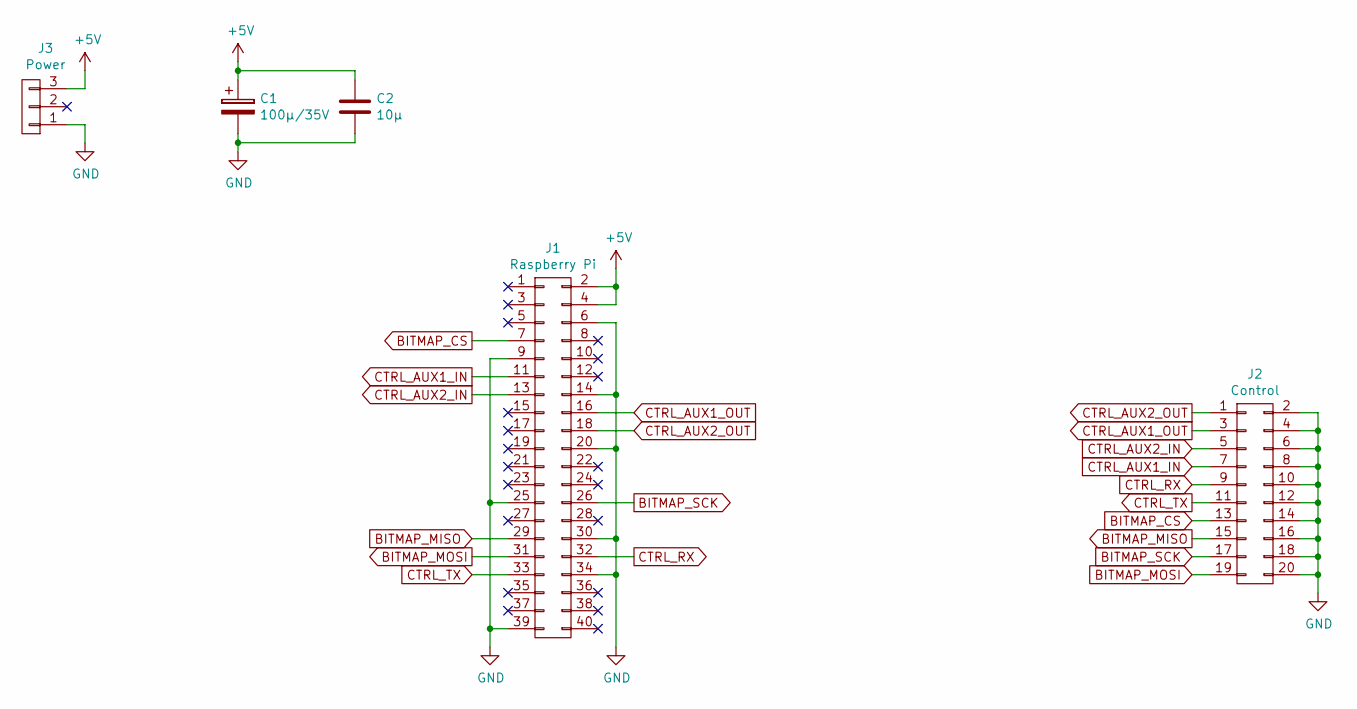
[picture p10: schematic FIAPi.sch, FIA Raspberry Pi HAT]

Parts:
C1: 100µ/35V; CP_Elec_6.3x7.7
C2: 10µ; C_0805
J1: Raspberry Pi; Socket_Strip_Straight_2x20
J2: Control; IDC_Header_Straight_20pins
J3: Power; Connector_DEGSON_DG246-3.81_3pin

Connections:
+5V: C1.1, C2.1, J1.2, J1.4, J3.3
BITMAP_CS: J1.7, J2.13
BITMAP_MISO: J1.29, J2.15
BITMAP_MOSI: J1.31, J2.19
BITMAP_SCK: J1.26, J2.17
CTRL_AUX1_IN: J1.11, J2.7
CTRL_AUX1_OUT: J1.16, J2.3
CTRL_AUX2_IN: J1.13, J2.5
CTRL_AUX2_OUT: J1.18, J2.1
CTRL_RX: J1.32, J2.9
CTRL_TX: J1.33, J2.11
GND: C1.2, C2.2, J1.6, J1.9, J1.14, J1.20, J1.25, J1.30, J1.34, J1.39, J2.2, J2.4, J2.6, J2.8, J2.10, J2.12, J2.14, J2.16, J2.18, J2.20, J3.1

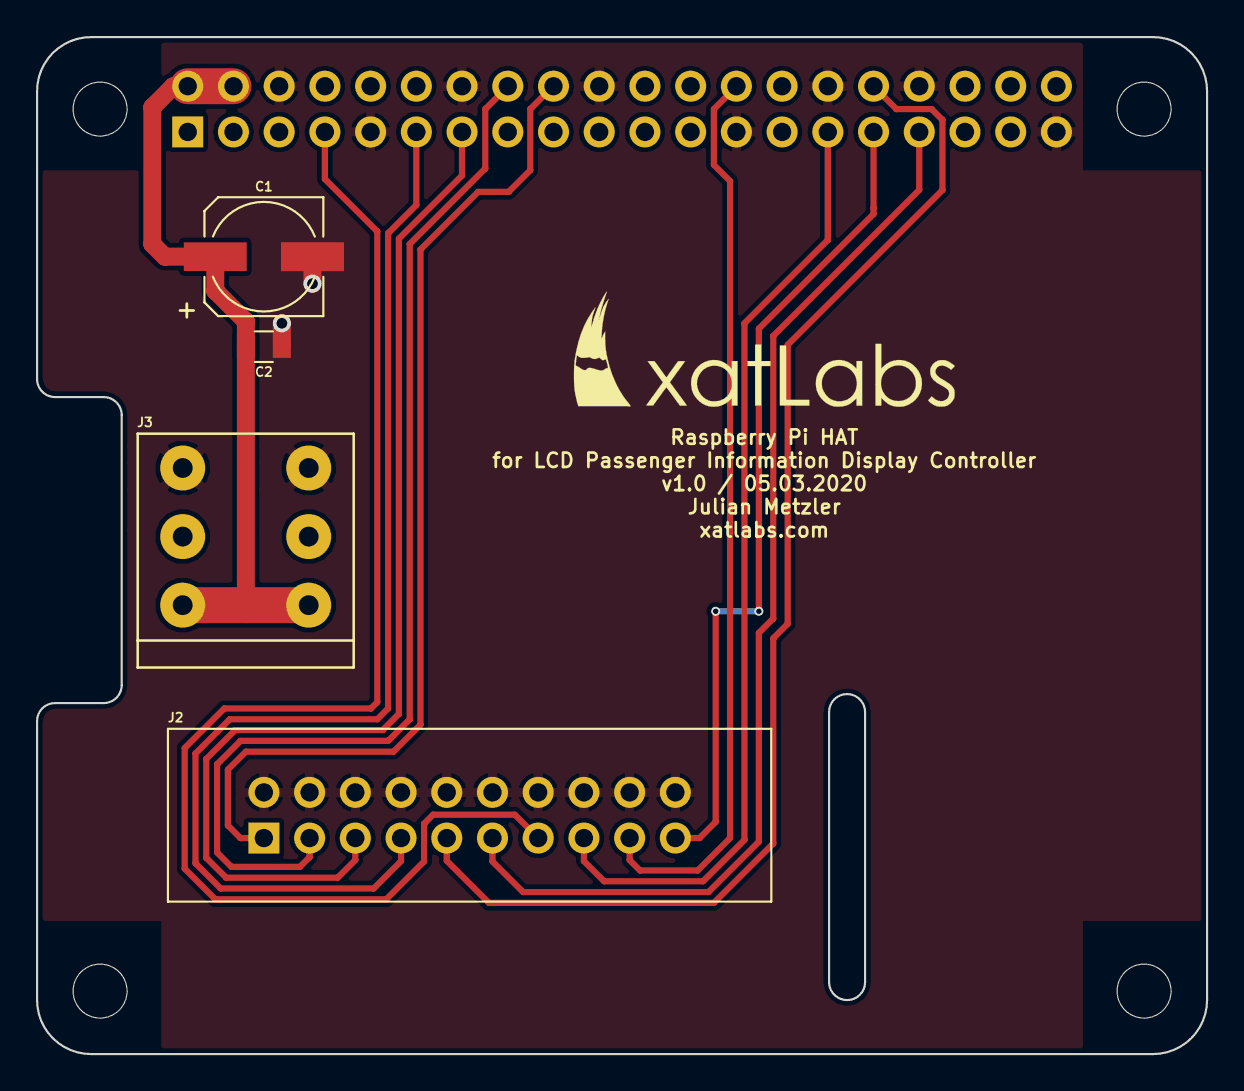
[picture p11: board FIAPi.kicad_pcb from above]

Board: 2 copper layers, 65.0 x 56.5 mm, 5 parts (1 on the bottom side), 12 nets.

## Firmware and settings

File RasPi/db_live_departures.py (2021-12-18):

import argparse
import datetime
import json
import random
import requests
import time
import traceback

from deutschebahn import DBInfoscreen, DS100
from layout_renderer import LayoutRenderer
from fia_control import FIA, FIAEmulator
from utils import TimeoutError, timeout

from db_common import *
from local_settings import *

if BL_AUX_IN_1_ENABLED:
    import threading
    import RPi.GPIO as gpio


LAST_DATA_HASH = 0
COACH_ORDER_CACHE = {}


def bl_timer(fia):
    if fia.get_backlight_state() == 1:
        print("Backlight is already on, aborting")
        return
    print("Enabling backlight")
    fia.set_backlight_state(1)
    time.sleep(BL_AUX_IN_1_TIME)
    print("Disabling backlight")
    fia.set_backlight_state(0)


def on_bl_button_pressed(pin, fia):
    print("Backlight button pressed")
    bl_thread = threading.Thread(target=bl_timer, kwargs={'fia': fia})
    bl_thread.start()


def train_type_filter(train, train_types):
    cur_type = train['train'].split()[0]
    for tt in train_types:
        if cur_type == tt:
            return True
    return False


def show_departures(dbi, ds100, fia, renderer, config, auto_clear_scroll_buf = False):
    global LAST_DATA_HASH
    global COACH_ORDER_CACHE
    
    @timeout(10)
    def _get_trains(station_code):
        return dbi.get_trains(station_code)
    
    @timeout(10)
    def _get_coach_order(train_number, departure):
        return dbi.get_coach_order(train_number, departure)
    
    mode = config.get('mode', 'detail')
    station = config.get('station')
    display_station = config.get('display_station')
    train_types = config.get('train_types')
    platform = config.get('platform', 'all')
    layout_single = config.get('layout_single', {})
    layout_double = config.get('layout_double', {})
    layout_list = config.get('layout_list', {})
    replacement_map = config.get('replacement_map')
    duration = config.get('duration', 10)
    
    if type(layout_single) is str:
        with open(layout_single, 'r', encoding='utf-8') as f:
            layout_single = json.load(f)
    
    if type(layout_double) is str:
        with open(layout_double, 'r', encoding='utf-8') as f:
            layout_double = json.load(f)
    
    if type(layout_list) is str:
        with open(layout_list, 'r', encoding='utf-8') as f:
            layout_list = json.load(f)
    
    if type(replacement_map) is str:
        with open(replacement_map, 'r', encoding='utf-8') as f:
            replacement_map = json.load(f)
    
    
    random_station = station == "RANDOM"
    num_tries = 0
    while num_tries < 5:
        num_tries += 1
        if random_station:
            filter_func = lambda s: s['type'] == "Bf" and not s['code'][0] in ("X", "Z")
            station_code = random.choice([code for code, data in ds100.filter(filter_func).items()])
            print("Trying station {}".format(station_code))
            trains = dbi.calc_real_times(_get_trains(station_code))
        else:
            station_code = station
            trains = dbi.calc_real_times(_get_trains(station))
        trains = filter(lambda t: t['actualDeparture'] is not None, trains)
        trains = filter(lambda t: not t['train'].startswith("Bus SEV"), trains)
        if train_types:
            trains = filter(lambda t: train_type_filter(t, train_types), trains)
        if platform != "all":
            trains = filter(lambda t: t['scheduledPlatform'] == platform, trains)
        trains = list(trains)
        if trains or not random_station:
            break
    trains = sorted(trains, key=dbi.time_sort)
    
    if mode == 'detail':
        # Filter out double trains (same platform, time and destination)
        uids = set()
        new_trains = []
        for train in trains:
            uid = "{platform} {time} {destination}".format(platform=train.get('platform', ""), time=train.get('scheduledDeparture', ""), destination=train.get('destination', ""))
            if uid not in uids:
                uids.add(uid)
                new_trains.append(train)
        trains = new_trains
        
        # If there are at least two trains, check if there are two trains that are coupled
        double_pair = None
        if len(trains) >= 2:
            search_length = min(len(trains), 5)
            x = 0
            for y in range(search_length):
                if x == y:
                    continue
                if trains[x]['scheduledDeparture'] == trains[y]['scheduledDeparture'] and trains[x]['scheduledPlatform'] == trains[y]['scheduledPlatform']:
                    double_pair = (x, y)
                    break
        
        double = False
        if double_pair:
            double = True
            x, y = double_pair
            main_trains = [trains[x], trains[y]]
            next_trains_set = set([i for i, t in enumerate(trains)])
            next_trains_set -= set(double_pair)
            next_trains_idx = list(next_trains_set)
            next_trains = []
            if len(next_trains_idx) >= 1:
                next_trains.append(trains[next_trains_idx[0]])
            if len(next_trains_idx) >= 2:
                next_trains.append(trains[next_trains_idx[1]])
        elif len(trains) >= 1:
            main_trains = [trains[0]]
            next_trains = []
            if len(trains) >= 2:
                next_trains.append(trains[1])
            if len(trains) >= 3:
                next_trains.append(trains[2])
        else:
            main_trains = []
            next_trains = []
        
        has_main_trains = bool(main_trains)
        has_next_trains = bool(next_trains)
        
        main_trains += [{}] * (2 - len(main_trains))
        next_trains += [{}] * (2 - len(next_trains))
        
        if not has_main_trains:
            data = {
                'placeholders': {
                    'station': display_station,
                    'destination': "Kein Zugverkehr",
                    'next_trains': "",
                }
            }
            if random_station:
                data['placeholders']['station'] = ds100.get(station_code).get('short_name')
            layout = layout_single
        else:
            delay_next_1 = dbi.round_delay(next_trains[0].get('delayDeparture', 0))
            delay_next_2 = dbi.round_delay(next_trains[1].get('delayDeparture', 0))
            
            if delay_next_1 == -1:
                delay_next_1 = ">210"
            if delay_next_2 == -1:
                delay_next_2 = ">210"
            
            if double:
                train1 = main_trains[0]
                train2 = main_trains[1]
                
                data = {
                    'placeholders': {
                        'station': display_station,
                        'platform': str(train1.get('scheduledPlatform')),
                        'departure_1': train1.get('scheduledDeparture'),
                        'info': get_info_long(train1),
                        'train_1': get_train_number(train1.get('train', ""), replacement_map),
                        'via_1': " \xb4 ".join(get_via(train1, replacement_map)),
                        'destination_1': get_destination_name(train1.get('destination', ""), replacement_map),
                        'departure_2': train2.get('scheduledDeparture'),
                        'train_2': get_train_number(train2.get('train', ""), replacement_map),
                        'via_2': " \xb4 ".join(get_via(train2, replacement_map)),
                        'destination_2': get_destination_name(train2.get('destination', ""), replacement_map),
                        'next_train_1_departure': next_trains[0].get('scheduledDeparture'),
                        'next_train_1_delay': "+{}".format(delay_next_1) if delay_next_1 else "",
                        'next_train_2_departure': next_trains[1].get('scheduledDeparture'),
                        'next_train_2_delay': "+{}".format(delay_next_2) if delay_next_2 else "",
                        'next_train_1_train': get_train_number(next_trains[0].get('train', ""), replacement_map),
                        'next_train_2_train': get_train_number(next_trains[1].get('train', ""), replacement_map),
                        'next_train_1_destination': get_destination_name(next_trains[0].get('destination', ""), replacement_map),
                        'next_train_1_info': get_info_short(next_trains[0]),
                        'next_train_2_destination': get_destination_name(next_trains[1].get('destination', ""), replacement_map),
                        'next_train_2_info': get_info_short(next_trains[1])
                    }
                }
                
                if random_station:
                    data['placeholders']['station'] = ds100.get(station_code).get('short_name')
                if not has_next_trains:
                    data['placeholders']['next_trains'] = ""
                layout = layout_double
            else:
                train = main_trains[0]
                if "F" in train.get('trainClasses', []):
                    if train.get('train') in COACH_ORDER_CACHE:
                        order_sections, order_coaches = COACH_ORDER_CACHE[train.get('train')]
                    else:
                        train_number = int(train.get('train').split()[1])
                        departure_time = datetime.datetime.strptime(train.get('scheduledDeparture'), "%H:%M").time()
                        if departure_time < datetime.datetime.now().time():
                            departure_date = datetime.date.today() + datetime.timedelta(days=1)
                        else:
                            departure_date = datetime.date.today()
                        departure_dt = datetime.datetime.combine(departure_date, departure_time)
                        departure = departure_dt.strftime("%Y%m%d%H%M")
                        order_data = _get_coach_order(train_number, departure)
                        #print(order_data)
                        order_sections, order_coaches = get_coach_order_strings(order_data)
                        #print(order_sections, order_coaches)
                        COACH_ORDER_CACHE[train.get('train')] = (order_sections, order_coaches)
                else:
                    order_sections = None
                    order_coaches = None
                
                data = {
                    'placeholders': {
                        'station': display_station,
                        'platform': str(train.get('scheduledPlatform')),
                        'departure': train.get('scheduledDeparture'),
                        'info': get_info_long(train),
                        'train': get_train_number(train.get('train', ""), replacement_map),
                        'order_sections': "\x25\x26\x27\x28\x29\x2a\x2b" if order_sections else None,
                        'order_coaches': order_coaches,
                        'via': " \xb4 ".join(get_via(train, replacement_map)),
                        'destination': get_destination_name(train.get('destination', ""), replacement_map),
                        'next_train_1_departure': next_trains[0].get('scheduledDeparture'),
                        'next_train_1_delay': "+{}".format(delay_next_1) if delay_next_1 else "",
                        'next_train_2_departure': next_trains[1].get('scheduledDeparture'),
                        'next_train_2_delay': "+{}".format(delay_next_2) if delay_next_2 else "",
                        'next_train_1_train': get_train_number(next_trains[0].get('train', ""), replacement_map),
                        'next_train_2_train': get_train_number(next_trains[1].get('train', ""), replacement_map),
                        'next_train_1_destination': get_destination_name(next_trains[0].get('destination', ""), replacement_map),
                        'next_train_1_info': get_info_short(next_trains[0]),
                        'next_train_2_destination': get_destination_name(next_trains[1].get('destination', ""), replacement_map),
                        'next_train_2_info': get_info_short(next_trains[1])
                    }
                }
                if random_station:
                    data['placeholders']['station'] = ds100.get(station_code).get('short_name')
                if not has_next_trains:
                    data['placeholders']['next_trains'] = ""
                layout = layout_single
    
    elif mode == 'list':
        layout = layout_list
        data = {
            'placeholders': {}
        }
        for i in range(min(len(trains), 7)):
            data['placeholders']['departure_{}'.format(i+1)] = trains[i].get('scheduledDeparture')
            data['placeholders']['train_{}'.format(i+1)] = get_train_number(trains[i].get('train', ""), replacement_map)
            data['placeholders']['via_{}'.format(i+1)] = " \xb4 ".join(get_via(trains[i], replacement_map))
            data['placeholders']['destination_{}'.format(i+1)] = get_destination_name(trains[i].get('destination', ""), replacement_map)
            data['placeholders']['platform_{}'.format(i+1)] = str(trains[i].get('scheduledPlatform'))
            data['placeholders']['info_{}'.format(i+1)] = get_info_long(trains[i])
    
    data_hash = hash(json.dumps(data, sort_keys=True))
    if data_hash != LAST_DATA_HASH:
        renderer.free_scroll_buffers()
        renderer.display(layout, data)
        LAST_DATA_HASH = data_hash
    time.sleep(duration)
    if auto_clear_scroll_buf:
        renderer.free_scroll_buffers()


def main():
    parser = argparse.ArgumentParser(add_help=False)
    parser.add_argument('--layout-single', '-ls', required=False, type=str)
    parser.add_argument('--layout-double', '-ld', required=False, type=str)
    parser.add_argument('--layout-list', '-ll', required=False, type=str)
    parser.add_argument('--font-dir', '-fd', required=True, type=str)
    parser.add_argument('--station', '-s', required=True, type=str)
    parser.add_argument('--train-types', '-tt', required=False, type=str)
    parser.add_argument('--platform', '-p', required=False, type=str, default="all")
    parser.add_argument('--replacement-map', '-rm', required=False, type=str)
    parser.add_argument('--emulate', '-e', action='store_true', help="Run in emulation mode")
    parser.add_argument('--dbi-host', required=False, type=str, default="dbf.finalrewind.org")
    parser.add_argument('--mode', '-t', choices=('detail', 'list'), default='list', type=str)
    args = parser.parse_args()
    
    if args.emulate:
        fia = FIAEmulator(width=DISPLAY_WIDTH, height=DISPLAY_HEIGHT)
    else:
        fia = FIA("/dev/ttyAMA1", (3, 0), width=DISPLAY_WIDTH, height=DISPLAY_HEIGHT)

    if BL_AUX_IN_1_ENABLED:
        time.sleep(3)
        gpio.setmode(gpio.BCM)
        gpio.setup(FIA.PIN_CTRL_AUX1_OUT, gpio.IN)
        gpio.add_event_detect(FIA.PIN_CTRL_AUX1_OUT, gpio.RISING, callback=lambda pin: on_bl_button_pressed(pin, fia))
        fia.set_backlight_state(0)
    
    renderer = LayoutRenderer(args.font_dir, fia=fia)
    
    dbi = DBInfoscreen(args.dbi_host)
    ds100 = DS100()

    if args.train_types:
        train_types = args.train_types.split(",")
    else:
        train_types = []
    
    if args.replacement_map:
        with open(args.replacement_map, 'r') as f:
            replacement_map = json.load(f)
    else:
        replacement_map = None
    
    if args.mode == 'detail':
        if args.layout_single:
            with open(args.layout_single, 'r', encoding='utf-8') as f:
                layout_single = json.load(f)
        else:
            print("Missing --layout-single. Aborting.")
            return
        
        if args.layout_double:
            with open(args.layout_double, 'r', encoding='utf-8') as f:
                layout_double = json.load(f)
        else:
            layout_double = layout_single
        
        config = {
            'mode': 'detail',
            'station': args.station,
            'train_types': args.train_types,
            'platform': args.platform,
            'layout_single': layout_single,
            'layout_double': layout_double,
            'layout_list': None,
            'replacement_map': replacement_map,
            'duration': 30
        }
    
    elif args.mode == 'list':
        if args.layout_list:
            with open(args.layout_list, 'r', encoding='utf-8') as f:
                layout_list = json.load(f)
        else:
            print("Missing --layout-list. Aborting.")
            return
        
        config = {
            'mode': 'list',
            'station': args.station,
            'train_types': args.train_types,
            'platform': args.platform,
            'layout_single': None,
            'layout_double': None,
            'layout_list': layout_list,
            'replacement_map': replacement_map,
            'duration': 30
        }
    
    while True:
        try:
            show_departures(dbi, ds100, fia, renderer, config)
        except KeyboardInterrupt:
            renderer.free_scroll_buffers()
            fia.exit()
            break
        except:
            traceback.print_exc()
            time.sleep(10)

if __name__ == "__main__":
    main()

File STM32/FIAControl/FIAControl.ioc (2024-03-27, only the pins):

PD12.GPIO_Label=FAN_3
PC12.Signal=SPI3_MOSI
PC6.GPIO_Label=TEMP_1_ONEWIRE
PB13.Signal=GPIO_Output
PD6.GPIO_Label=STATUS_LED_2
PE6.GPIO_Label=LCD4_MOSI
PB6.Signal=I2C1_SCL
PC7.Signal=GPIO_Input
PC3.Signal=SPI2_MOSI
PD8.Signal=GPIO_Output
PE5.Signal=SPI5_MISO
PE1.Signal=GPIO_Input
PB12.GPIO_Label=LCD3_SCK
PC4.GPIO_Label=LCD1_LATCH
PE9.Signal=S_TIM1_CH1
PE4.GPIO_Label=BITMAP_CS
PE2.Signal=UART10_RX
PE10.Signal=GPIO_Input
PA0.Signal=ADCx_IN0
PB9.Signal=GPIO_Output
PD12.Signal=GPIO_Output
PE12.GPIO_Label=LCD4_SCK
PE10.GPIO_Label=DOOR_B
PA4.GPIO_Label=CONTRAST_1
PD15.Signal=GPIO_Output
PD9.GPIO_Label=HEATER_2
PC6.Signal=GPIO_Input
PD10.Signal=GPIO_Output
PB8.GPIO_Label=CTRL_AUX2_OUT
PE8.GPIO_Label=DOOR_A
PE9.GPIO_Label=LCD_FRAME
PB10.Signal=SPI2_SCK
PA5.Signal=COMP_DAC2_group
PE1.GPIO_Label=CTRL_AUX1_IN
PE14.Signal=SPI5_MOSI
PE15.Signal=GPIO_Output
PE8.Signal=GPIO_Input
PA1.GPIO_Label=BRIGHTNESS_IN_2
PC7.GPIO_Label=TEMP_2_ONEWIRE
PA4.Signal=COMP_DAC1_group
PA5.GPIO_Label=CONTRAST_2
PD11.Signal=GPIO_Output
PE5.GPIO_Label=BITMAP_MISO
PC12.GPIO_Label=LCD3_MOSI
PE3.Signal=UART10_TX
PC3.GPIO_Label=LCD2_MOSI
PB0.Signal=SPI5_SCK
Mcu.UserName=STM32F413VGTx
PE11.GPIO_Label=LCD4_LATCH
PA0.GPIO_Label=BRIGHTNESS_IN_1
PB0.GPIO_Label=BITMAP_SCK
PB13.GPIO_Label=LCD3_LATCH
PD13.Signal=GPIO_Output
PD11.GPIO_Label=FAN_2
PB7.Signal=I2C1_SDA
PE4.Signal=GPXTI4
PD13.GPIO_Label=FAN_4
PD5.GPIO_Label=STATUS_LED_1
PE0.GPIO_Label=CTRL_AUX2_IN
PE7.Signal=GPXTI7
PD6.Signal=GPIO_Output
PE2.GPIO_Label=CTRL_RX
PB3.GPIO_Label=LCD1_SCK
PD15.GPIO_Label=AUX_OUT_1
PB9.GPIO_Label=CTRL_AUX1_OUT
PC9.GPIO_Label=BUTTON_2
PC8.Signal=GPIO_Input
PC4.Signal=GPIO_Output
PE14.GPIO_Label=BITMAP_MOSI
PD9.Signal=GPIO_Output
PD5.Signal=GPIO_Output
PD8.GPIO_Label=HEATER_1
PC8.GPIO_Label=BUTTON_1
PA13.Signal=SYS_JTMS-SWDIO
PE15.GPIO_Label=LCD2_LATCH
PB10.GPIO_Label=LCD2_SCK
PD10.GPIO_Label=FAN_1
PE11.Signal=GPIO_Output
PA1.Signal=ADCx_IN1
PD14.GPIO_Label=LIGHT
PE6.Signal=SPI4_MOSI
PE0.Signal=GPIO_Input
PE7.GPIO_Label=AUX_IN_1
PE12.Signal=SPI4_SCK
PD14.Signal=GPIO_Output
PB3.Signal=SPI1_SCK
PA7.GPIO_Label=LCD1_MOSI
PA14.Signal=SYS_JTCK-SWCLK
PB8.Signal=GPIO_Output
PE3.GPIO_Label=CTRL_TX
PC9.Signal=GPIO_Input
PB12.Signal=SPI3_SCK
PA7.Signal=SPI1_MOSI

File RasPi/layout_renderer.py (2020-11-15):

import argparse
import json
import math
import os

from fia_control import FIA, FIAEmulator, FIAError
from PIL import Image, ImageOps, ImageDraw

from local_settings import *


class ScrollBuffer:    
    def __init__(self, fia, side, disp_x, disp_y, disp_w, disp_h, int_w, int_h, sc_off_x = 0, sc_off_y = 0, sc_sp_x = 0, sc_sp_y = 0, sc_st_x = 0, sc_st_y = 0):
        self.fia = fia
        self.side = side
        self.disp_x = disp_x
        self.disp_y = disp_y
        self.disp_w = disp_w
        self.disp_h = disp_h
        self.int_w = int_w
        self.int_h = int_h
        self.sc_off_x = sc_off_x or 0
        self.sc_off_y = sc_off_y or 0
        self.sc_sp_x = sc_sp_x or 0
        self.sc_sp_y = sc_sp_y or 0
        self.sc_st_x = sc_st_x or 0
        self.sc_st_y = sc_st_y or 0
        self.id = None
    
    def update(self):
        if self.id is None:
            raise FIAError("Can't update unallocated scroll buffer")
        return self.fia.update_scroll_buffer(self.id, self.side, self.disp_x, self.disp_y, self.disp_w, self.disp_h, self.sc_off_x, self.sc_off_y, self.sc_sp_x, self.sc_sp_y, self.sc_st_x, self.sc_st_y)
    
    def create(self):
        self.id = self.fia.create_scroll_buffer(self.side, self.disp_x, self.disp_y, self.disp_w, self.disp_h, self.int_w, self.int_h, self.sc_off_x, self.sc_off_y, self.sc_sp_x, self.sc_sp_y, self.sc_st_x, self.sc_st_y)
    
    def delete(self):
        if self.id is None:
            raise FIAError("Can't delete unallocated scroll buffer")
        return self.fia.delete_scroll_buffer(self.id)
    
    def send_img(self, img):
        if self.id is None:
            raise FIAError("Can't send image to unallocated scroll buffer")
        
        w, h = img.size
        if w != self.int_w or h != self.int_h:
            raise FIAError("Scroll buffer image doesn't match allocated dimensions")
        
        dest_buf = self.fia.get_destination_buffer()
        try:
            self.fia.set_destination_buffer(self.id)
            self.fia.send_image(img, auto_fit=False)
        finally:
            # Restore old destination buffer
            self.fia.set_destination_buffer(dest_buf)


class LayoutRenderer:
    MAX_FIELD_WIDTH = 10000
    CHAR_MAP = {
        
    }
    
    SIDE_LUT = {
        'a': FIA.SIDE_A,
        'b': FIA.SIDE_B,
        'both': FIA.SIDE_BOTH
    }
    
    def __init__(self, font_dir, fia = None):
        self.font_dir = font_dir
        self.fia = fia
        self.img_mode = 'L'
        self.img_bg = 255
        self.img_fg = 0
        self.scroll_buffers = []
    
    def get_font_dir(self, font, size):
        return os.path.join(self.font_dir, font, "size_{}".format(size))
    
    def get_char_filename(self, font, size, code):
        return os.path.join(self.get_font_dir(font, size), "{:x}.bmp".format(code))
    
    def get_char_code(self, char):
        if char in self.CHAR_MAP:
            code = self.CHAR_MAP[char]
        else:
            code = ord(char)
        return code
    
    def get_font_metadata(self, font, size):
        metadata_file = os.path.join(self.get_font_dir(font, size), "metadata.json")
        with open(metadata_file, 'r') as f:
            metadata = json.load(f)
        return metadata
    
    def get_text_size(self, font, size, text, h_spacing, v_spacing):
        metadata = self.get_font_metadata(font, size)
        char_sizes = metadata['char_sizes']
        width = 0
        height = 0
        lines = text.splitlines()
        for line_idx, line in enumerate(lines):
            max_height = 0
            for char_idx, char in enumerate(line):
                key = str(self.get_char_code(char))
                if key in char_sizes:
                    cw, ch = char_sizes[key]
                    width += cw
                    if ch > max_height:
                        max_height = ch
                if char_idx < len(line) - 1:
                    width += h_spacing
            height += max_height
            if line_idx < len(lines) - 1:
                height += v_spacing
        return width, height
    
    def wrap_text(self, font, size, width, text, h_spacing, break_words):
        line_width, line_height = self.get_text_size(font, size, text, h_spacing, 0)
        if line_width <= width:
            #print("all good!")
            return [text]
        
        # We need to drop some words from the end
        lines = []
        words_dropped = 0
        words = text.split(" ")
        #print("=" * 40)
        #print("words:", words)
        while True:
            words_dropped += 1
            partial_line = " ".join(words[:-words_dropped])
            #print("partial_line:", partial_line)
            if not partial_line:
                # We dropped all words, this means even just one word is already too wide.
                # So we need to start breaking in the middle of a word if desired
                if break_words:
                    # Yep, break in the middle of a word
                    chars_dropped = 0
                    word = words[0]
                    empty = False
                    while True:
                        chars_dropped += 1
                        partial_word = word[:-chars_dropped]
                        #print("partial_word:", partial_word)
                        if not partial_word:
                            # Even a single character is too wide. Just give up at this point.
                            #print("char break fail")
                            if not word:
                                # The "word" is just an empty string
                                empty = True
                                partial_word = ""
                                word_remainder = ""
                            else:
                                partial_word = word[0]
                                word_remainder = word[1:]
                            break
                        line_width, line_height = self.get_text_size(font, size, partial_word, h_spacing, 0)
                        if line_width <= width:
                            word_remainder = word[-chars_dropped:]
                            break
                    lines.append(partial_word)
                    if empty:
                        remainder = word_remainder + " ".join(words[1:])
                    else:
                        remainder = word_remainder + " " + " ".join(words[1:])
                    #print("recursing, remainder:", remainder)
                    lines.extend(self.wrap_text(font, size, width, remainder, h_spacing, break_words))
                    break
                else:
                    # Nope, just accept cutting off the word
                    lines.append(words[0])
                    remainder = " ".join(words[1:])
                    #print("word break fail")
                    #print("recursing, remainder:", remainder)
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

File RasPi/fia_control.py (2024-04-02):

import serial
import time

# For real hardware, only available on RasPi
try:
    import spidev
    _HAS_SPIDEV = True
except ImportError:
    _HAS_SPIDEV = False

from PIL import Image, ImageSequence

# For emulator
import threading
import numpy as np
import tkinter as tk
from PIL import ImageTk


class FIAError(Exception):
    pass


class FIA:
    SIDE_A = 0x01
    SIDE_B = 0x02
    SIDE_BOTH = 0x03
    
    BUF_SCROLL = 0x80
    BUF_MASK = 0x40
    BUF_DYN = 0x20
    
    SCROLL_BUF_ERR_MASK = 0x10
    SCROLL_BUF_ERR_SIZE = 1
    SCROLL_BUF_ERR_COUNT = 2
    
    UART_CMD_NULL = 0x00
    UART_CMD_MCU_RESET = 0x01
    
    UART_CMD_SET_BACKLIGHT_STATE = 0x10
    UART_CMD_GET_BACKLIGHT_STATE = 0x11
    UART_CMD_SET_BACKLIGHT_BASE_BRIGHTNESS = 0x12
    UART_CMD_GET_BACKLIGHT_BASE_BRIGHTNESS = 0x13
    UART_CMD_GET_BACKLIGHT_BRIGHTNESS = 0x14
    
    UART_CMD_SET_HEATERS_STATE = 0x20
    UART_CMD_GET_HEATERS_STATE = 0x21
    UART_CMD_SET_CIRCULATION_FANS_STATE = 0x22
    UART_CMD_GET_CIRCULATION_FANS_STATE = 0x23
    UART_CMD_SET_HEAT_EXCHANGER_FAN_STATE = 0x24
    UART_CMD_GET_HEAT_EXCHANGER_FAN_STATE = 0x25
    UART_CMD_SET_BACKLIGHT_BALLAST_FANS_STATE = 0x26
    UART_CMD_GET_BACKLIGHT_BALLAST_FANS_STATE = 0x27
    
    UART_CMD_GET_DOOR_STATES = 0x30
    
    UART_CMD_GET_TEMPERATURES = 0x40
    UART_CMD_GET_HUMIDITY = 0x41
    UART_CMD_GET_ENV_BRIGHTNESS = 0x42
    
    UART_CMD_SET_LCD_CONTRAST = 0x50
    UART_CMD_GET_LCD_CONTRAST = 0x51
    
    UART_CMD_CREATE_SCROLL_BUFFER = 0x60
    UART_CMD_DELETE_SCROLL_BUFFER = 0x61
    UART_CMD_UPDATE_SCROLL_BUFFER = 0x62
    UART_CMD_SET_DESTINATION_BUFFER = 0x63
    UART_CMD_GET_DESTINATION_BUFFER = 0x64
    UART_CMD_SET_MASK_ENABLED = 0x65
    UART_CMD_GET_MASK_ENABLED = 0x66

    # Raspberry Pi BCM GPIO pin
    # Names as seen from the STM32
    PIN_CTRL_AUX1_OUT = 23
    PIN_CTRL_AUX2_OUT = 24
    PIN_CTRL_AUX1_IN = 17
    PIN_CTRL_AUX2_IN = 27
    
    def __init__(self, uart_port, spi_port, uart_baud = 115200, uart_timeout = 1.0, spi_clock = 5000000, width = 480, height = 128, panel_width = 96, panel_height = 64):
        if not _HAS_SPIDEV:
            raise RuntimeError("spidev module not installed. If you are running this on a PC, use FIAEmulator instead.")
        self.uart = serial.Serial(uart_port, baudrate=uart_baud, timeout=uart_timeout)
        self.spi = spidev.SpiDev()
        self.spi.open(*spi_port)
        self.spi.max_speed_hz = spi_clock
        self.width = width
        self.height = height
        self.panel_width = panel_width
        self.panel_height = panel_height
    
    def exit(self):
        pass
    
    def send_uart_command_raw(self, raw_command):
        # Just send a raw UART command
        self.uart.write(bytearray(raw_command))
    
    def calculate_uart_checksum(self, data):
        checksum = 0x7F
        for byte in data:
            checksum ^= byte
        return checksum
    
    def read_uart_response(self):
        header = self.uart.read(2)
        if header[0] != 0xFF:
            return None
        length = header[1]
        payload = self.uart.read(length)
        if len(payload) != length:
            print("err len")
            return None
        checksum = payload[-1]
        if checksum != self.calculate_uart_checksum(payload[:-1]):
            print("err chk")
            return None
        #print(header + payload)
        return bytearray(payload[:-1])
    
    def send_uart_command(self, command, data = [], expect_response = True):
        # Send UART command and return response
        assert len(data) <= 254
        raw_command = [0xFF, len(data) + 2, command]
        raw_command += data
        checksum = self.calculate_uart_checksum([command] + data)
        raw_command.append(checksum)
        self.send_uart_command_raw(raw_command)
        if expect_response:
            return self.read_uart_response()
        else:
            return None
    
    def twos_comp(self, val, bits):
        if val < 0:
            return val + 2**bits
        else:
            return val
    
    def inv_twos_comp(self, val, bits):
        if val & (1 << (bits-1)):
            return val - 2**bits
        else:
            return val
    
    def null_cmd(self):
        resp = self.send_uart_command(self.UART_CMD_NULL)
    
    def mcu_reset(self):
        resp = self.send_uart_command(self.UART_CMD_MCU_RESET, expect_response=False)
    
    def set_backlight_state(self, state):
        resp = self.send_uart_command(self.UART_CMD_SET_BACKLIGHT_STATE, [state])
    
    def get_backlight_state(self):
        resp = self.send_uart_command(self.UART_CMD_GET_BACKLIGHT_STATE)
        return resp[0]
    
    def set_backlight_base_brightness(self, side_a, side_b):
        side_a = self.twos_comp(side_a, 16)
        side_b = self.twos_comp(side_b, 16)
        params = [side_a >> 8, side_a & 0xFF, side_b >> 8, side_b & 0xFF]
        resp = self.send_uart_command(self.UART_CMD_SET_BACKLIGHT_BASE_BRIGHTNESS, params)
    
    def get_backlight_base_brightness(self):
        resp = self.send_uart_command(self.UART_CMD_GET_BACKLIGHT_BASE_BRIGHTNESS)
        side_a = self.inv_twos_comp((resp[0] << 8) | resp[1], 16)
        side_b = self.inv_twos_comp((resp[2] << 8) | resp[3], 16)
        return side_a, side_b
    
    def get_backlight_brightness(self):
        resp = self.send_uart_command(self.UART_CMD_GET_BACKLIGHT_BRIGHTNESS)
        side_a = (resp[0] << 8) | resp[1]
        side_b = (resp[2] << 8) | resp[3]
        return side_a, side_b
    
    def get_env_brightness(self):
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

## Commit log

2020-03-02 First revision of STM32 controller board
    [FIAControl.csv, FIAControl.kicad_pcb, FIAControl.sch]
2020-03-02 Prepared CubeMX project for STM32 controller board
2020-03-02 Added Gerber dirs to .gitignore
2020-03-05 Added Raspberry Pi HAT (FIAPi) for connecting to the FIAControl board
    [FIAPi.kicad_pcb, FIAPi.sch, HAT.dxf]
2020-03-05 Fixed incorrect label directions on Control header in FIAControl schematic
    [FIAControl.sch]
2020-03-21 Added Raspberry Pi high-level stuff
2020-03-21 Added first barely functional version of FIAControl STM32 firmware
2020-03-21 Added old LCD test project (STM32 BluePill based)
2020-03-21 Renamed Raspberry Pi folder
2020-03-21 STM32: added more comments and improved structure
2020-03-21 STM32: Reworked side-dependent code and added brightness 0 on door open
    [fia.c, fia.h, main.c]
2020-03-21 STM32: Added DS18B20 temperature sensor readout
2020-03-22 STM32: Added UART protocol
2020-03-22 STM32: Implemented I²C Temp&Humidity sensor, added internal Temp. sensor
2020-03-22 RasPi: Added temperature logger and status monitor, renamed layouts
2020-03-22 STM32: Improved handling of backlight brightness, added cmds to get cur. & env. brightness
2020-03-24 STM32: Added MCU Reset UART command
    [uart_commands.c]
2020-03-24 RasPi: Added MCU Reset UART command and fixed DB live departure script
    [db_live_departures.py, fia_control.py]
2020-04-02 RasPi: Added OpenOCD server configuration for remote debugging / flashing
    [stlink.cfg]
2020-04-02 STM32: Updated PIO config for remote debugging / flashing
2020-04-02 RasPi: Added back ST-LINK USB IDs and removed unnecessary WORKAREA definition from OpenOCD config
    [stlink.cfg]
2020-04-06 STM32: Tweaked LCD FR timer values for more accurate duty cycle
2020-04-06 STM32: Added LCD contrast UART commands
2020-04-06 RasPi: Added LCD contrast UART commands
2020-04-06 Hardware: Updated todo, added LTSpice sim of LCD contrast power stage
2020-04-07 STM32: Only update brightness DACs when door status or ADC average changed
2020-04-12 STM32: Changed startup sequence to be less harsh on the power supply
2020-04-13 STM32: Rewrote bitmap rendering to work with regular col-major bitmaps
    [LCD Bitmap Mapping.xlsx]
2020-04-13 STM32: Moved main code to fia.c, prepared SPI Rx CS functionality
2020-04-13 STM32: Changed GET_ENV_BRIGHTNESS UART command byte and added documentation
    [UART Protocol.xlsx]
2020-04-14 STM32: Implemented proper SPI Rx CS handling (Bitmap Rx)
2020-04-14 RasPi: Updated UART commands acc. to 605bb0a and removed MCU reset from DB dep. screen
    [db_live_departures.py, fia_control.py]
2020-04-18 STM32: Added correct linker file path
2020-04-18 STM32: Added temp. regulation and prepared support for scroll buffers, minor restructuring
    [UART Protocol.xlsx]
2020-04-18 STM32: Fixed wrong temperature on sensor error
    [ds18b20.c, fia.c]
2020-04-19 STM32: Separated LCD update code, prepared mask buffer support, changed temp. reg. thresholds
2020-04-19 STM32: Updated malloc to allow reallocating blocks of exact same size
2020-04-19 STM32: Updated temperature regulation values
2020-04-25 STM32: Fixed incorrect LCD data on different panel counts, made FR freq configurable
    [FIAControl.ioc, aditech.c, fia.h]
2020-04-25 STM32: Added AUX IN 1 interrupt (propagated to FIAPi)
2020-04-25 STM32: Added auto-format config file
2020-05-07 RasPi: Added frame dropping to display_image.py
2020-05-10 STM32: Added more preparation for scroll buffers, renamed variable
2020-05-10 STM32: Fixed temperature regulation criteria
    [fia.c]
2020-05-10 STM32: Changed default contrast
2020-05-14 Added temperature measurement spreadsheet
    [Temperature Measurements.xlsx, temperatures.csv]
2020-05-14 STM32: Disable fans when door is open
2020-07-03 RasPi: Fix render_image missing parameter
    [layout_renderer.py]
2020-07-04 STM32: Add -O3 build flag
2020-07-04 STM32: Scroll buffer rendering, mask buffers as bitmap targets
2020-07-05 STM32: Actual scroll implementation, update protocol doc
    [UART Protocol.xlsx]
2020-07-05 RasPi: Update lib with new STM32 changes, improve interactive.py
2020-07-08 STM32: Make mask optional, reorder cmds, add GET_DESTINATION_BUFFER cmd
    [UART Protocol.xlsx]
2020-07-19 STM32: Decrease BL ballast temp (after 2 broken ballasts)
    [fia.h]
2020-07-20 Add interactive BOMs
    [FIAControl.kicad_pcb]
2020-07-20 Dark mode in BOMs, name change
    [FIAControl.kicad_pcb, FIAControl.sch]
2020-07-26 STM32: Add display format defines
2020-07-26 RasPi: Add train type filter to live departures
2020-07-26 RasPi: Add some station replacements
    [db_common.py]
2020-07-29 RasPi: Add more replacements
    [db_common.py]
2020-07-31 RasPi: Restructure replacement system to use individual json files
    [db_common.py, db_live_departures.py]
2020-08-13 RasPi: Add frame colour to emulator
2020-08-25 RasPi: Fix encoding in layouts for event display
    [event_display.py]
2020-08-27 RasPi: Fix rendering lines and rects when render_boxes is on
    [layout_renderer.py]
2020-08-27 RasPi: Webserver: Fix font choices
    [wsgi.py]
2020-08-27 RasPi: Add telegram app for event display, fix layouts
    [event_display.py, telegram_bot.py]
2020-08-27 RasPi: Fix telegram sorting order in event display
    [event_display.py]
2020-08-28 RasPi: Remove filter in telegram bot
2020-08-28 RasPi: Add error handling in event script
    [event_display.py]
2020-08-28 RasPi: Add socket default timeout to event script
2020-08-28 Fix additional deletions, reorder things
    [event_display.py]
2020-08-28 RasPi: Remove stray debug prints
2020-10-18 RasPi: Add custom route replacements
    [db_common.py, db_live_departures.py]
2020-10-18 STM32: Increase humidity thresholds
2020-11-15 RasPi: Fix exception when rendering layout to file with layout_renderer
    [layout_renderer.py]
2020-11-15 STM32: Add splash screens, use build configs instead of config.h
2022-01-02 RasPi: Improve error handling in mqtt_light
    [mqtt_light.py]
2024-03-26 Make UART_MAX_PAYLOAD_LENGTH as small as needed instead of 255
2024-03-27 Rename custom malloc/free implementations to avoid confusion with builtins
    [fia.c]
2024-03-27 Bugfix: UART ring buffer peek index didn't wrap around
    [uart_protocol.c]
2024-03-27 Enable watchdog timer
2024-04-02 STM32: Add product_line field to board definition
2024-04-02 STM32: Pin platform version, fix wrong define
